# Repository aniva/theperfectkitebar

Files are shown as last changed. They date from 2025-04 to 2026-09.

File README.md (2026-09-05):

# ThePerfectKiteBar (TPKB)

A **DIY kite control bar with shared design files** designed for **kite-foil enthusiasts** who value flexibility, customization, and field serviceability.

Development began in **2023**, driven by the lack of suitable off-the-shelf products—most commercial options were either too expensive, overly complex, unnecessarily heavy, or built around identical designs across multiple brands.
The first functional version of TPKB was **tested in Spring 2024**, followed by multiple iterative refinements based on real-world user experience.

Key design priorities include:
- Minimal weight without compromising strength
- Full **field-serviceability** with common tools
- **Low-cost manufacturing** using accessible 3D printing services
- Easy **spare part replacement**
- **Glove-friendly operation**, especially in cold water (5°C and below)
- Seamless usability in both **cold northern climates** and **tropical destinations** (e.g., the Caribbean)

---

## Project Purpose

ThePerfectKiteBar is a hardware design project focused on designing and sharing components of a kite control bar system optimized for kite-foiling.

This project is intended for:

- DIY enthusiasts
- Riders seeking lightweight or custom solutions
- Experimental design exploration
- Field replacement and customization of bar components

All parts are designed with parametric flexibility in mind—allowing for adaptation to different materials, manufacturing methods, and rope/tube sizes.

---

## License and Project Management

Design files and documentation are shared under [CC BY-NC 4.0](LICENSE.md), which requires attribution and restricts commercial use.

See [Contributing](CONTRIBUTING.md) for the change workflow and local checks, and [Validation Status](docs/validation.md) for recorded testing status and outstanding validation work.

## Project Organization and Directory Structure

The main hardware components of the project are organized under the `/hardware/` directory:

- `/hardware/bar/` → Bar components, including the main tube, end pieces, and center inserts
- `/hardware/swivel/` → Swivel component for untwisting lines
- `/hardware/quick_release/` → The quick release safety system
- `/hardware/trim/` → Depower trim system, including the V-splitter
- `/hardware/tools/` → Jigs and tools for assembly

Each component has its own folder containing:

- Its own `README.md` file with detailed specifications
- Subfolders indicating key design constraints (tube diameter, bearing type, rope diameter, etc.)
- Variants reflecting different design approaches

---

## Design Philosophy: Variant vs Version

| Term | Meaning | How it's handled |
| --- | --- | --- |
| Variant | Different design direction or conceptual approach | Separate folder or filename indication |
| Version | Evolution of the same variant (small changes, tweaks, improvements) | Managed via Git version control |

**Example Filename Breakdown:**

```text
bar/carbon_tube_od24_id22mm/bar_end/leader_line_3mm/variant_7/bar-end_24_22_sls.*
```

- `bar` folder = part of the bar (vs QR etc.)
- `carbon_tube_od24_id22mm` = must use carbon tube with these OD/ID dimensions
- `leader_line_3mm` = must use 3mm leader (steering) lines 
- `variant` = 7 
- `version` = _git commit id_

---

## Navigation Guide

To explore any component:

1. Navigate to `hardware/<component_name>/` and open the `README.md` file in that directory
2. Inside you will find:
   - Part purpose and function
   - Design constraints and specifications
   - 3D printing instructions
   - Assembly notes and requirements
   - Images and previews
   - Available variants

**Component Links:**

- [Bar](hardware/bar/README.md)
- [Swivel](hardware/swivel/README.md)
- [Quick Release](hardware/quick_release/README.md)
- [Trim](hardware/trim/README.md)
- [Tools](hardware/tools/README.md)
- [Rope Splicing & Cutting Dimensions Guide](docs/rope_dimensions.md)
- [Interactive Splicing & Sizing Calculator](https://raw.githack.com/aniva/theperfectkitebar/main/docs/rope_calculator.html)
- [Bungee & Accessory Sizing Guide](https://raw.githack.com/aniva/theperfectkitebar/main/docs/rope_calculator.html)

---

## General 3D Print Material Selection Guide

Material selection must consider ductility, impact resistance, print orientation, and cyclic loading as well as tensile strength. The recommendations below incorporate the expanded JLC3DP SLS and MJF catalog; supplier specifications were checked on **2026-09-05**.

**3301PA is the recommended SLS choice for new bar ends and center inserts**, including white parts previously specified in 1172 Pro. **PA11-HP is preferred for new V-splitters carrying direct line tension, with PA12-HP retained as the existing alternative.** PA12-HP remains the baseline for cleat bases. Consider PA12S-HP for lightly loaded MJF accessories when the actual quote offers a saving.

The project previously reported multi-season field use of 3201PA-F from -20°C to +30°C in freshwater, seawater, and snow. That experience does not transfer automatically to another material. The newer recommendations are material-selection decisions, not recorded TPKB field validation; see [Validation Status](docs/validation.md). Component-specific geometry, metal hardware, and assembly requirements still apply.

### Material Recommendations by Use Case

| Part / Component | Recommended Material | Manufacturing Technology | Notes |
|---|---|---|---|
| Bar ends and center inserts, including white parts | [3301PA Nylon](https://jlc3dp.com/help/article/3301pa-nylon) | SLS | Recommended for new builds; 48 MPa tensile strength and 30% elongation. Higher listed elongation than 1172 Pro, but not than the current 3201PA-F specification. Verify fit, line wear, and impact behavior on the finished part. |
| Existing black SLS parts / established material option | [3201PA-F Nylon](https://jlc3dp.com/help/article/3201pa-f-nylon) | SLS | Retain as an alternative backed by the project's reported field experience. Current supplier figures are 44 MPa and 35% elongation. |
| Existing white SLS parts | [Precimid 1172 Pro](https://jlc3dp.com/help/article/precimid-1172-pro) | SLS | Legacy white option; 46 MPa and 8–15% elongation. Prefer evaluating 3301PA for new bar ends and center inserts. |
| V-splitters carrying direct kite-line tension | [PA11-HP Nylon](https://jlc3dp.com/help/article/pa11-hp-nylon) preferred; [PA12-HP](https://jlc3dp.com/help/article/pa12-hp-nylon) existing alternative | MJF | Prefer PA11-HP for new builds based on its higher listed tensile strength, elongation, and notched impact strength. Validate the finished part under representative line loads, including sustained-load creep and line-hole wear. Do not substitute PA12S solely to reduce cost. |
| Cleat bases | [PA12-HP Nylon](https://jlc3dp.com/help/article/pa12-hp-nylon) | MJF | Retain the existing baseline; evaluate PA11-HP separately for fit and loaded operation. |
| Lightly loaded housings, covers, and slider blocks without significant shock loading | [PA12S-HP Nylon](https://jlc3dp.com/help/article/pa12s-hp-nylon) | MJF | Potential cost-saving choice with a finer surface texture. Account for orientation: elongation is 12% in XY but only 5% in Z. Compare actual part quotes. |
| Polymer components requiring greater ductility | [PA11-HP Nylon](https://jlc3dp.com/help/article/pa11-hp-nylon) | MJF | Candidate for testing: 52 MPa and 50% elongation. A QR housing substitution requires assembly and release-function testing. This is not a recommendation to replace metal pins or load-bearing metal mechanisms with nylon. |
| Swivel metal parts (housing and shaft) | [Titanium TC4](https://jlc3dp.com/help/article/titanium-tc4) or [316L Stainless Steel](https://jlc3dp.com/help/article/316L-Stainless-Steel) | SLM | Titanium for lower weight; otherwise 316L stainless steel, following component specifications. |
| Quick Release (QR) mechanism flat parts | Titanium sheet | Laser or waterjet cutting | Use the exact thickness specified in the component instructions. |
| Assembly tools | Refer to [Tools](hardware/tools/README.md) | SLM and SLA | Follow each tool's requirements; CBY resin remains an economical option for suitable jig adapters and presser feet. |

### Supplier Property Comparison

These are supplier coupon-test values, not allowable loads for the printed components. XY and Z identify print orientation; test methods and specimen conditioning differ between materials. Higher elongation alone does not establish better fatigue life or impact performance.

| Technology | Material / Supplier Source | Tensile Strength | Elongation at Break | Selection Notes |
|---|---|---|---|---|
| MJF | [PA12-HP](https://jlc3dp.com/help/article/pa12-hp-nylon) | 48 MPa | 20% | Existing structural baseline. |
| MJF | [PA12S-HP](https://jlc3dp.com/help/article/pa12s-hp-nylon) | 45 MPa XY; 43 MPa Z | 12% XY; 5% Z | Finer texture; lower ductility. Its listed 1700 MPa tensile modulus is lower than PA12-HP's 1800 MPa. |
| MJF | [PA11-HP](https://jlc3dp.com/help/article/pa11-hp-nylon) | 52 MPa XY/Z | 50% XYZ | Preferred for new V-splitters; validate the finished component. |
| MJF | [PAC-HP](https://jlc3dp.com/help/article/pac-hp-nylon) | Not listed on linked page | Not listed on linked page | JLC3DP describes full-color nylon for models and prototypes, not carbon-fiber-filled nylon. Excluded from structural recommendations. |
| SLS | [3201PA-F](https://jlc3dp.com/help/article/3201pa-f-nylon) | 44 MPa | 35% | Current figures differ from the supplied research's 45–48 MPa and 10–15%. |
| SLS | [1172 Pro](https://jlc3dp.com/help/article/precimid-1172-pro) | 46 MPa | 8–15% | Existing white material. |
| SLS | [3301PA](https://jlc3dp.com/help/article/3301pa-nylon) | 48 MPa | 30% | White; selected for new bar ends and center inserts. |
| SLS | [3401GB](https://jlc3dp.com/help/article/3401gb-nylon) | 42 MPa | 8% | 2500 MPa tensile modulus. Not selected for impact-prone kite-bar parts because this project prioritizes ductility over increased stiffness. |

### Cost, Exposure, and Manufacturing Notes

- **Cost:** JLC3DP lists starting prices of $1 for the linked PA12-HP, PA12S-HP, PA11-HP, 3201PA-F, 1172 Pro, and 3301PA materials. These minimum prices do not establish equal finished-part costs or a guaranteed PA12S saving; compare quotes for the same geometry and quantity.
- **Marine exposure:** The linked specifications do not establish comparative long-term UV, saltwater, cold-water, or fatigue performance for these TPKB parts. Record representative exposure and loading results before describing a replacement material as field-proven. PA11's ductility is not a guarantee against fracture.
- **Print review:** Evaluate supplier dimensional or wall-thickness warnings against the affected part's fit and loading requirements. Do not dismiss a warning solely because a previous print worked. See the [example supplier warning](images/jlc3dp_warning.jpeg).

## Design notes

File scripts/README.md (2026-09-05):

# Developer Automation & Git Hooks

This directory contains utility scripts and Git hooks that automate local CAD file management, keep documentation in sync with cloud storage, and clean up workspace metadata.

## The Big Picture: Why are hooks needed?

Git tracks manufacturing exports such as `.stl`, `.step`, and `.dxf`. Editable `.shapr` sources are excluded from Git and hosted in the Google Cloud Storage (GCS) bucket `theperfectkitebar-cad-assets`.

To make collaboration smooth, we use scripts and a Git hook to:
1. **Sync Assets (manual script)**: Fetch latest CAD files from GCS to your local `hardware/` directory.
2. **Synchronize Docs**: Keep download links, file hashes (MD5), and modification dates in README files automatically in sync with the files stored on GCS.
3. **Clean Metadata**: Strip hidden OS and cloud sync files (e.g. Windows `:Zone.Identifier` or Dropbox attributes) from the repository before commits.

---

## Installation

To set up the automated hooks on your local machine, run:

```bash
./scripts/hooks/install_hooks.sh
```

This script installs executable hooks in Git’s configured hooks directory, using absolute symlinks into this checkout. It repairs stale symlinks and refuses to overwrite an existing regular hook file. Rerun it after moving the checkout.

---

## Script Reference

### Hooks
* **`install_hooks.sh`**: Installs symlinks from `.git/hooks/` to the project's scripts.
* **`pre-commit.sh`** (runs automatically before each commit):
  * Cleans up OS/Dropbox metadata files (`:Zone.Identifier`, `:com.dropbox.attrs`) to prevent Git pollution.
  * Runs `update_shapr_tables.py` to auto-generate markdown download tables in component READMEs.
  * Automatically stages READMEs whose generated tables change. This stages the entire file, so finish or separate unrelated README edits before committing.
  * Works without an interactive terminal and succeeds when no table updates are needed. If GCS metadata is unavailable, the updater reports it and leaves tables unchanged.

### Python Utilities
* **`update_shapr_tables.py`**:
  * Scans local directories for `.shapr` source files.
  * Fetches file metadata (MD5 hashes, last-modified dates) from the GCS JSON API.
  * Dynamically updates markdown tables inside READMEs between `<!-- BEGIN_SHAPR_TABLE -->` and `<!-- END_SHAPR_TABLE -->` tags.
* **`sync_from_gcs.py`**:
  * Syncs public GCS assets locally into your `hardware/` directory.
  * Compares local MD5 hashes with GCS metadata to perform smart, delta-only updates.
  * Backs up overwritten files into timestamped local `backup/` folders so you never lose local edits.

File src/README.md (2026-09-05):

# Google Cloud Infrastructure & Functions

This directory contains the Terraform configuration and Python Cloud Functions to deploy and manage the public asset hosting infrastructure for ThePerfectKiteBar.

## The Big Picture: Egress Cost Protection

Hosting CAD models (`.stl`, `.step`, `.shapr`) for public download on Google Cloud Storage (GCS) can lead to unpredictable bandwidth egress costs if the designs become popular. To ensure the project remains cost-controlled, this infrastructure automatically revokes public access when a budget limit is hit.

```mermaid
graph TD
    Alert[Budget Alert Exceeded] -->|Pub/Sub| DisableFn[disablePublicAccess Cloud Function]
    DisableFn -->|IAM Update| Bucket[(GCS Asset Bucket)]
    
    Scheduler[Cloud Scheduler Job <br/> 1st of the month] -->|HTTP POST| EnableFn[enablePublicAccess Cloud Function]
    EnableFn -->|IAM Update| Bucket
```

---

## Infrastructure Architecture

The infrastructure consists of:

1. **GCS Asset Bucket (`theperfectkitebar-cad-assets`)**: Public bucket where CAD files are stored and served.
2. **GCS Code Bucket (`theperfectkitebar-fn-code`)**: Private bucket where zipped Cloud Function code is uploaded.
3. **Pub/Sub Topic (`cad-budget-alerts`)**: Connects to the GCP Billing Budget so that alerts publish messages to this topic.
4. **Cloud Scheduler Job (`reenable-public-access`)**: Runs monthly to trigger the enabling function.

### Cloud Functions (Python 3.12 / Gen 2)

* **`disablePublicAccess`**:
  * **Trigger**: Subscribed to the `cad-budget-alerts` Pub/Sub topic.
  * **Action**: Parses the budget alert payload. If the display name matches the configured budget and the alert threshold is exceeded, it removes `allUsers` from the `roles/storage.objectViewer` binding on the asset bucket (effectively disabling public downloads).
* **`enablePublicAccess`**:
  * **Trigger**: HTTP POST endpoint.
  * **Action**: Adds the `allUsers` member back to the bucket's `roles/storage.objectViewer` policy binding, restoring public downloads.

---

## File Reference

* **`cad2gcp/`**: The primary Terraform module containing infrastructure resource definitions.
* **`cad2gcp/src/main.py`**: Function entry points that dispatch to the handlers.
* **`cad2gcp/src/disable_public_access.py`**: Budget-alert handler that removes public access.
* **`cad2gcp/src/enable_public_access.py`**: HTTP handler that restores public access.
* **`cad2gcp/variables.tf`**: Input variables, including the budget display name.

The Terraform module defines the Pub/Sub topic but does not create the billing budget. Configure that budget separately to publish to `cad-budget-alerts`, using the matching display name. These files describe the intended deployment; they do not establish its current live status.

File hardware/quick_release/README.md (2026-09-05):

# Quick release

The Quick Release (QR) is a critical safety component of the kite control system. This design focuses on reliability, ease of use (even with gloves in cold water), and field serviceability.

The mechanism consists of 3D-printed parts and flat-cut metal components.

-   **Case**: The main body of the QR is designed for SLS 3D printing in Nylon (e.g., PA12 or Precimid-1172 Pro for a white finish) for durability and impact resistance.
-   **Mechanism**: The internal flat parts are designed to be laser or waterjet cut from Grade 5 Titanium sheets of specific thicknesses (0.125" and 0.187") for maximum strength and corrosion resistance.

This directory contains variants of the QR system that accommodate different bolt sizes (M4 and M6) for attachment.

Below are two images showing the Quick Release in its closed (locked) and open (released) positions. It functions like any standard push-away quick release system used in kitesurfing.

<table>
  <tr>
    <td align="center"><strong>Closed Position</strong></td>
    <td align="center"><strong>Open Position</strong></td>
  </tr>
  <tr>
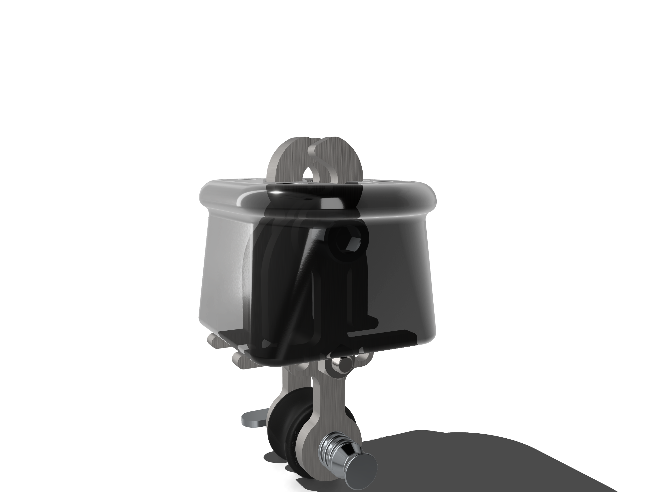
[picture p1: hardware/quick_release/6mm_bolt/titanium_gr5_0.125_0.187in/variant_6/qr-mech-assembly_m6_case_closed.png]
    <td></td>
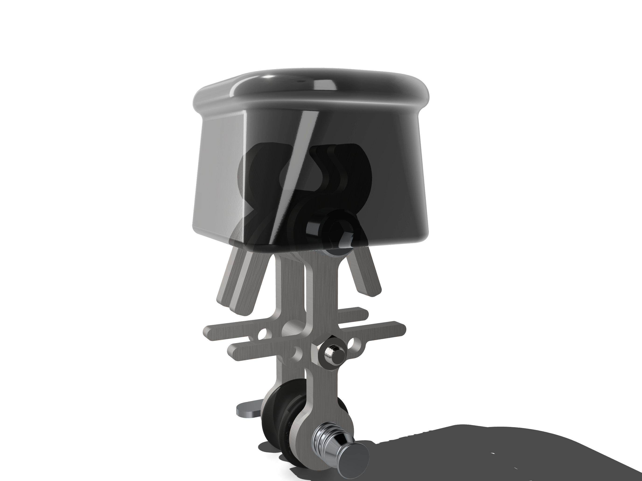
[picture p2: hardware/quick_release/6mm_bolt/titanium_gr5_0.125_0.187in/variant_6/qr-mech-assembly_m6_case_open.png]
    <td></td>
  </tr>
</table>

## Sizing (M4 vs. M6)

The M4 and M6 versions are functionally identical across all variants, with the only difference being the diameter of the attachment bolt.

-   **M4 Version**: A lighter-weight option suitable for most recreational riders.
-   **M6 Version**: A heavier-duty option suitable for heavier riders or more demanding conditions.

Note that for all variants, the upper nut (M4 or M6) that holds the claws must be installed permanently (e.g., using Loctite Threadlocker Red).

See [Validation Status](../../docs/validation.md) for recorded evidence and outstanding testing work.

## Variants

Variants 1 through 4 have been omitted, as they represent early design iterations that did not proceed to field testing.

### Variant 5 M4

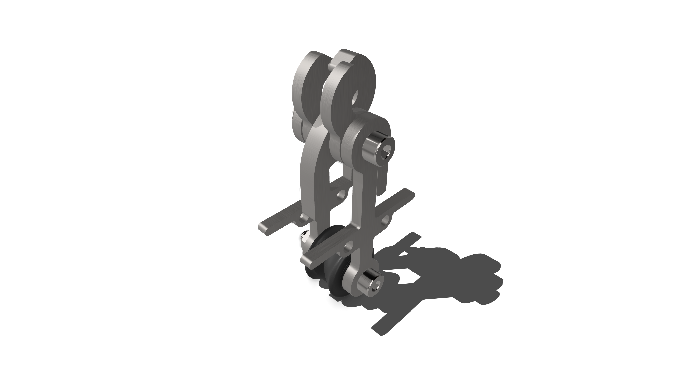
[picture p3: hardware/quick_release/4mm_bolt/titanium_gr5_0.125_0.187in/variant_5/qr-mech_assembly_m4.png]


This variant uses a permanent M4 bolt and nut to attach to the harness's sliding rope. It is recommended to use a thread-locking fluid (e.g., Loctite Threadlocker Red) to secure the nut.

Parts needed to build the **M4** version of this variant.

From any laser/waterjet cutting service (e.g., SendCutSend)

| File Name | Parameters | Quantity | Image
|---|---|---|---|
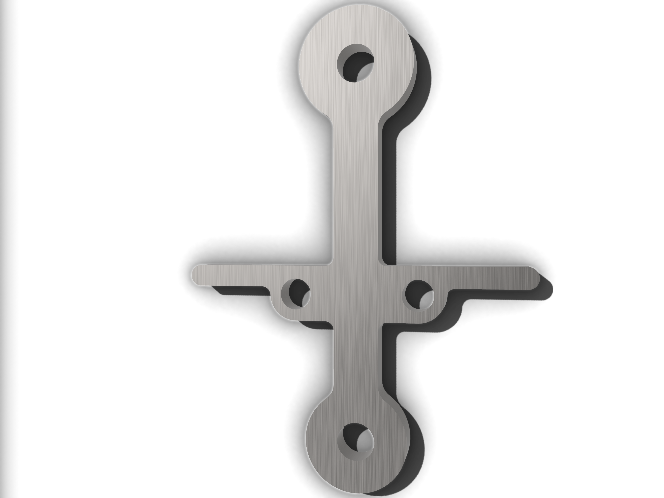
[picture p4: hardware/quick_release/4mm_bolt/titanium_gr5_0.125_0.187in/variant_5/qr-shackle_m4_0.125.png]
| [`qr-shackle_m4.dx`](./4mm_bolt/titanium_gr5_0.125_0.187in/variant_5/qr-shackle_m4.dxf) | Material: Grade 5 Titanium, Thickness: 0.125" | 2 pieces ||
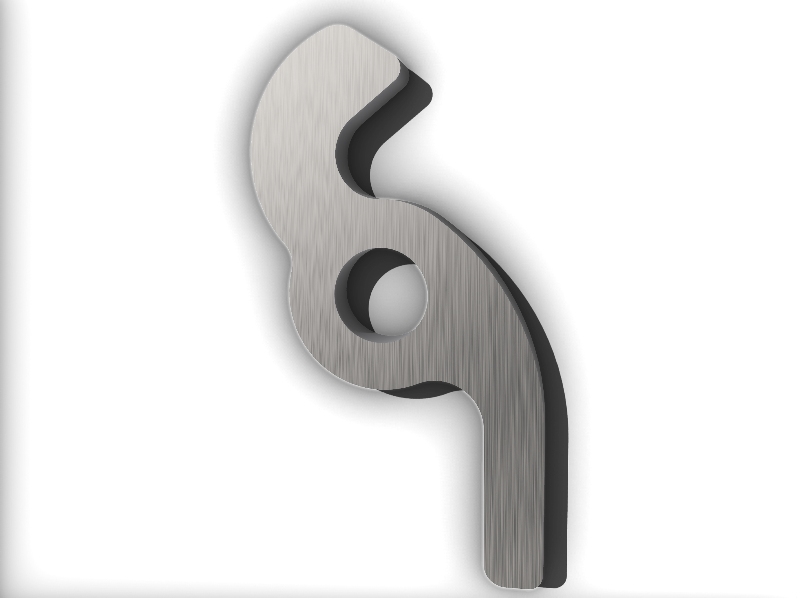
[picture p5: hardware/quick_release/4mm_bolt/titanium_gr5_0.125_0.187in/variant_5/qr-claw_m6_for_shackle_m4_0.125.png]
| [`qr-claw_m6_for_shackle_m4.dxf`](./4mm_bolt/titanium_gr5_0.125_0.187in/variant_5/qr-claw_m6_for_shackle_m4.dxf) | Material: Grade 5 Titanium, Thickness: 0.125" | 2 pieces ||
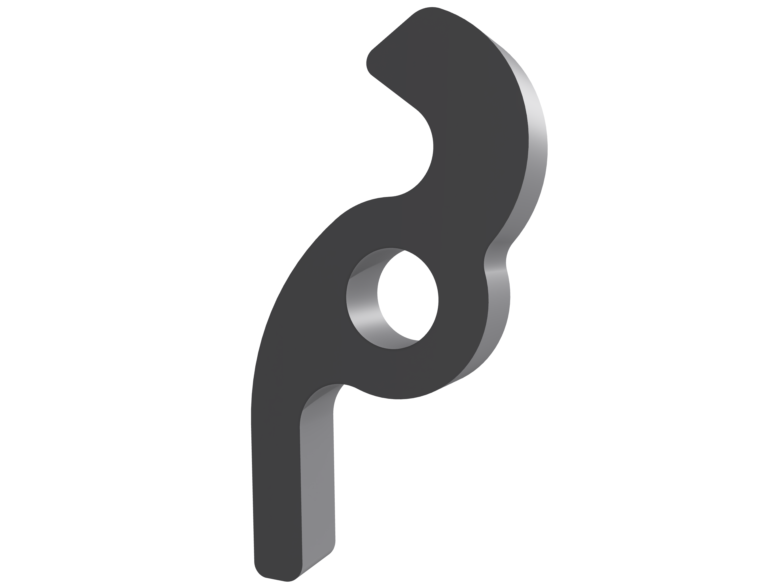
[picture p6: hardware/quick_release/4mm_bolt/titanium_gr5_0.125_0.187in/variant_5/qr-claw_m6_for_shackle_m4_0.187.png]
| [`qr-claw_m6_for_shackle_m4.dxf`](./4mm_bolt/titanium_gr5_0.125_0.187in/variant_5/qr-claw_m6_for_shackle_m4.dxf) | Material: Grade 5 Titanium, Thickness: 0.187" | 1 piece ||

From a print shop with SLS 3D printing technology (e.g., jlc3dp.com)

| File Name | Parameters | Quantity | Image |
|---|---|---|---|
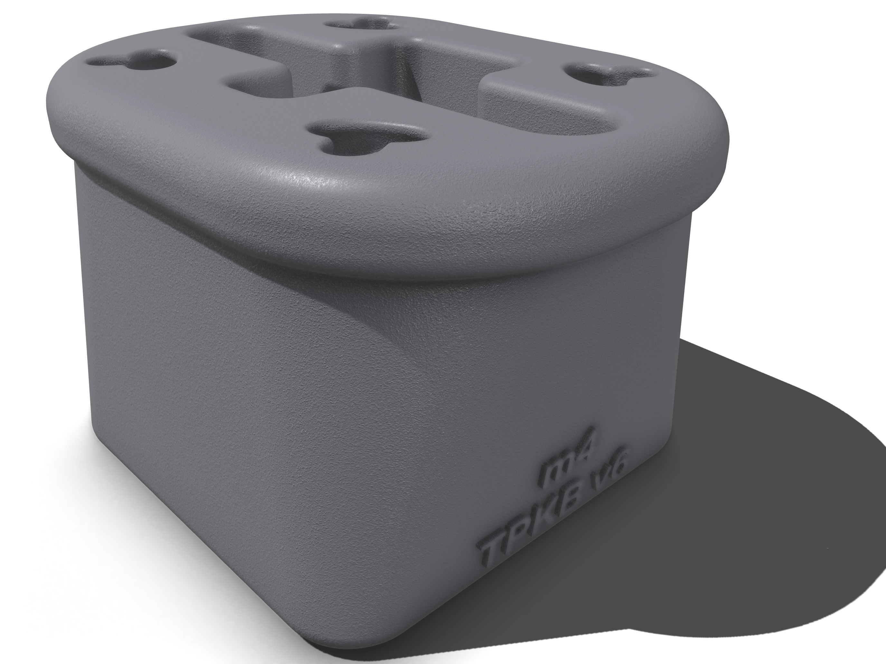
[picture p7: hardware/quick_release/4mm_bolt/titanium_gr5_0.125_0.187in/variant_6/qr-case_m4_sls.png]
| [`qr-case_m4_sls.stl`](./4mm_bolt/titanium_gr5_0.125_0.187in/variant_6/qr-case_m4_sls.stl) | Material 3201PA-F Nylon or 1172Pro Nylon | 1 piece || 
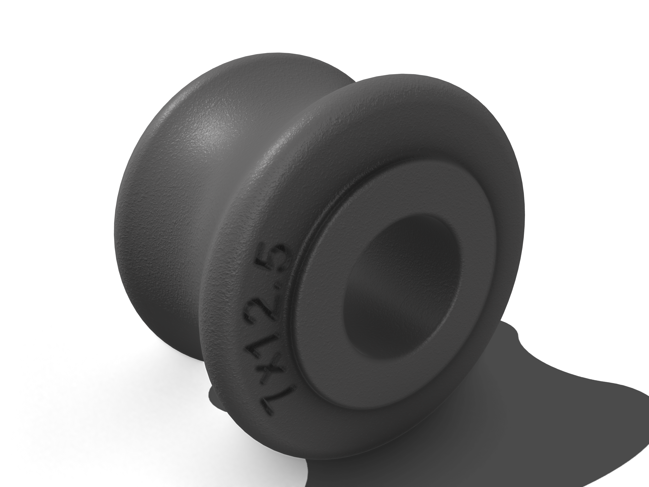
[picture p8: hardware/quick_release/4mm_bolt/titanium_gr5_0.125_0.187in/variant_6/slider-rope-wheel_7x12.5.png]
| [`slider-rope-wheel_7x12.5.stl`](./4mm_bolt/titanium_gr5_0.125_0.187in/variant_6/slider-rope-wheel_7x12.5.stl) | Material 3201PA-F Nylon or 1172Pro Nylon | 1 piece ||

Additional parts can be procured from hardware suppliers such as aliexpress.com, amazon.com, or McMaster-Carr.

- Marine grade stainless or titanium socket head bolts M4 lengh of 25mm - 2 bolts and 2 nuts
- Titanium tube for two 13mm spacers with an outer diameter (OD) of 6mm and an inner diameter (ID) of 4mm.
- 2.5mm Elastic Nylon Bungee Cord. A length of ~35cm (approx. 1 ft 2 in) is needed per QR. (Example: Paracord Planet Elastic Nylon Bungee and Shock Cord)

### Variant 5 M6

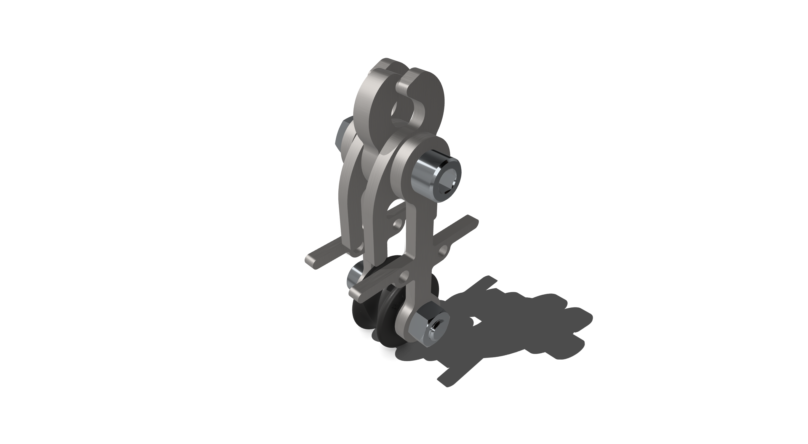
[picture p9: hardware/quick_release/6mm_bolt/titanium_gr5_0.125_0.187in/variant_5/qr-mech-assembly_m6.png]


This variant uses a permanent M6 bolt and nut to attach to the harness's sliding rope. It is recommended to use a thread-locking fluid (e.g., Loctite Threadlocker Red) to secure the nut.

Parts needed to build the **M6** version of this variant.

From any laser/waterjet cutting service (e.g., SendCutSend)

| File Name | Parameters | Quantity | Image |
|---|---|---|---|
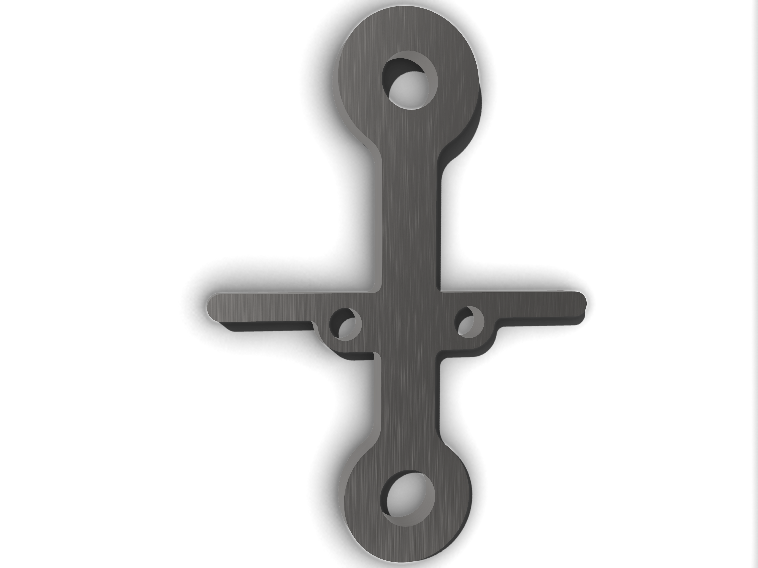
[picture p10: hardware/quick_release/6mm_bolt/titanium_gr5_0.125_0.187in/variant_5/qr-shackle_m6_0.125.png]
| [`qr-shackle_m6.dxf`](./6mm_bolt/titanium_gr5_0.125_0.187in/variant_5/qr-shackle_m6.dxf) | Material: Grade 5 Titanium, Thickness: 0.125" | 2 pieces ||
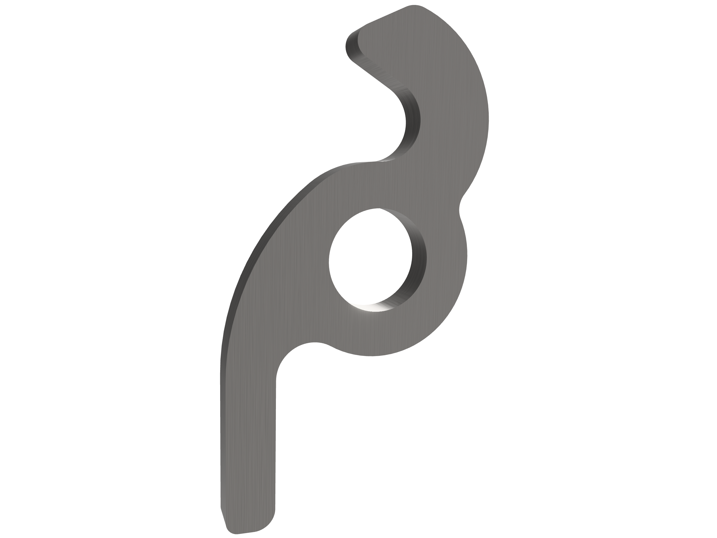
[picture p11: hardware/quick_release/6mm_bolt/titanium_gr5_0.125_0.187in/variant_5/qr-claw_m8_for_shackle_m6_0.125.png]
| [`qr-claw_m8_for_shackle_m6.dxf`](./6mm_bolt/titanium_gr5_0.125_0.187in/variant_5/qr-claw_m8_for_shackle_m6.dxf) | Material: Grade 5 Titanium, Thickness: 0.125" | 2 pieces ||
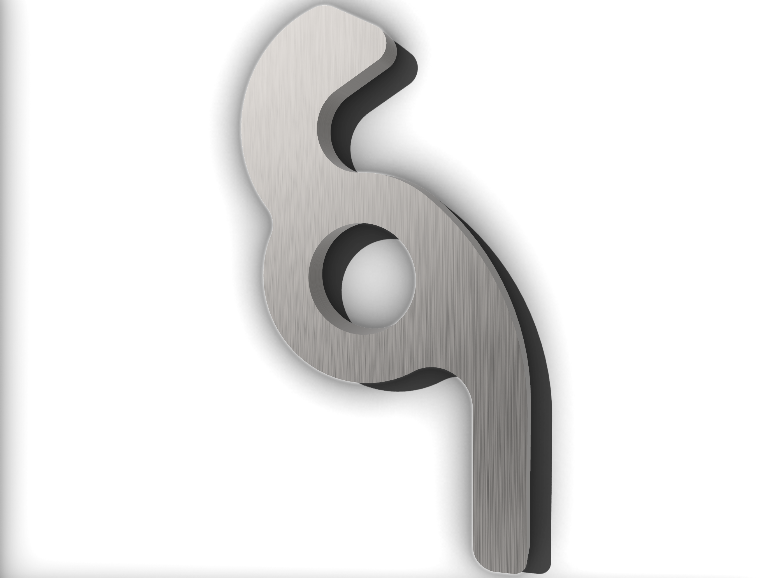
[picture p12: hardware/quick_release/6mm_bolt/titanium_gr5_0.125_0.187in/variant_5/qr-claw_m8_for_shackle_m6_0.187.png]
| [`qr-claw_m8_for_shackle_m6.dxf`](./6mm_bolt/titanium_gr5_0.125_0.187in/variant_5/qr-claw_m8_for_shackle_m6.dxf) | Material: Grade 5 Titanium, Thickness: 0.187" | 1 piece ||

From a print shop with SLS 3D printing technology (e.g., jlc3dp.com)

| File Name | Parameters | Quantity | Image |
|---|---|---|---|
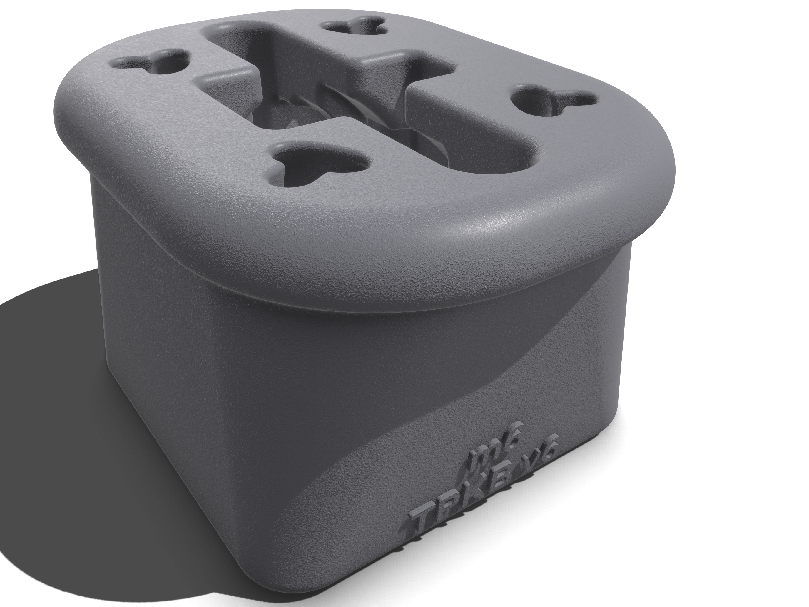
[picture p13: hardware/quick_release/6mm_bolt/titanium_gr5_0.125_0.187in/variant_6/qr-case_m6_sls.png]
| [`qr-case_m6_sls.stl`](./6mm_bolt/titanium_gr5_0.125_0.187in/variant_6/qr-case_m6_sls.stl) | Material 3201PA-F Nylon or 1172Pro Nylon | 1 piece || 
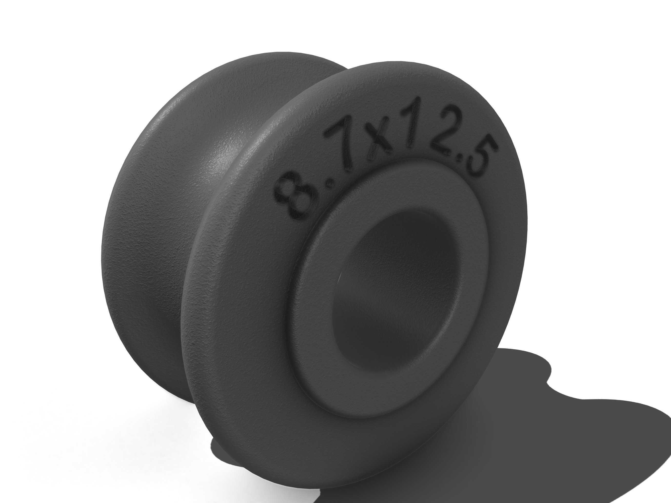
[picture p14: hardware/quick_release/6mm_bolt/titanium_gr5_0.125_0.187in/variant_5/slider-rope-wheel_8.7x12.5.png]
| [`slider-rope-wheel_8.7x12.5.stl`](./6mm_bolt/titanium_gr5_0.125_0.187in/variant_5/slider-rope-wheel_8.7x12.5.stl) | Material 3201PA-F Nylon or 1172Pro Nylon | 1 piece ||

Additional parts procured from hardware suppliers, e.g. aliexpress.com, amazon.com, or [macmastercarr](https://www.mcmaster.com/)

- Marine grade stainless or titanium socket head bolts M6 lengh of 25mm - 2 bolts and 2 nuts
- Titanium tube for two spacers of 13mm with OD 8mm and ID 6mm
- 2.5mm Elastic Nylon Bungee Cord. A length of ~35cm (approx. 1 ft 2 in) is needed per QR. (Example: Paracord Planet Elastic Nylon Bungee and Shock Cord)

### Variant 6

This variant uses a quick release pin, allowing for easy removal of the QR from a harness hook or sliding rope in the field.

To support QR structure an additional spacer with M4 bolt and nut used that must be instaled permanently (e.g.,using Loctite Threadlocker Red).

Note that all the claws are the same as for Variant 5 with correspoing M4 or M6 bolt and nut.

QR cases are also the same and rope wheel is of M4 version (because quick release pin diameter is M6, the M4 version of the wheel have hole diameter of 7mmm)

**Warning:** At the time of writing, this variant has not been field-tested. There is a risk that the quick release pin could be accidentally released during use. This would cause the kite to flag out on its safety line, potentially resulting in a long swim. Extreme riding and jumping are strongly discouraged until this variant has been thoroughly tested in various conditions.

### Variant 6 M4

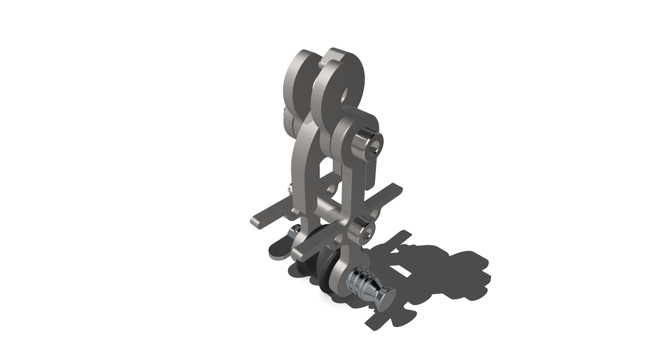
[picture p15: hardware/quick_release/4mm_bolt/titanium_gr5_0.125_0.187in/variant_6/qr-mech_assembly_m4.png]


Parts needed to build **M4** version of this variant.

From any laser/waterjet cutting service (e.g., SendCutSend)

| File Name | Parameters | Quantity | Image |
|---|---|---|---|
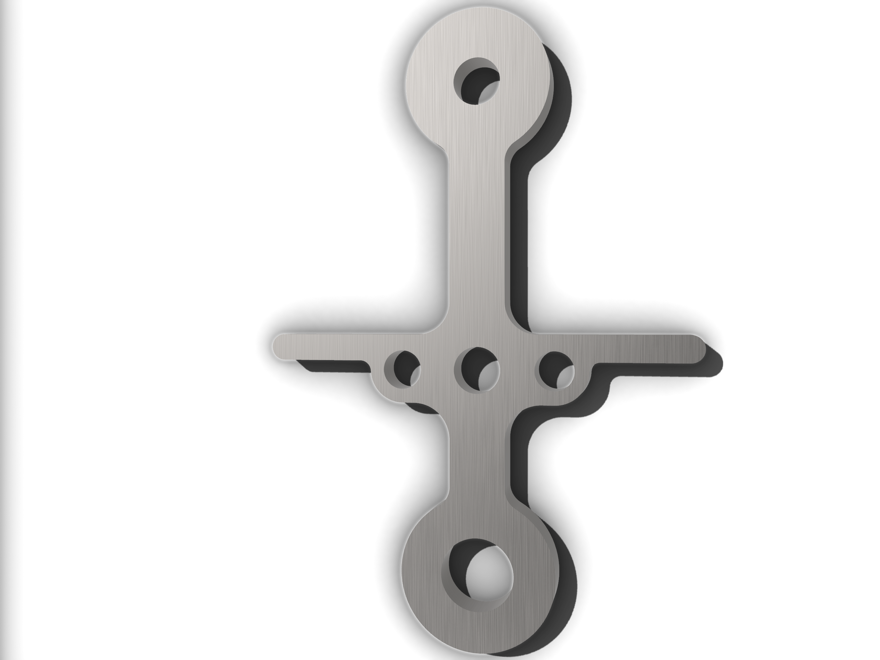
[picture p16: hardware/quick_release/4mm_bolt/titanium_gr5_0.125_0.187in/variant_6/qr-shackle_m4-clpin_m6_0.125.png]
| [`qr-shackle_m4-clpin_m6.dxf`](./4mm_bolt/titanium_gr5_0.125_0.187in/variant_6/qr-shackle_m4-clpin_m6.dxf) | Material: Grade 5 Titanium, Thickness: 0.125" | 2 pieces ||
| [`qr-claw_m6_for_shackle_m4.dxf`](./4mm_bolt/titanium_gr5_0.125_0.187in/variant_5/qr-claw_m6_for_shackle_m4.dxf) | Material: Grade 5 Titanium, Thickness: 0.125" | 2 pieces ||
| [`qr-claw_m6_for_shackle_m4.dxf`](./4mm_bolt/titanium_gr5_0.125_0.187in/variant_5/qr-claw_m6_for_shackle_m4.dxf) | Material: Grade 5 Titanium, Thickness: 0.187" | 1 piece ||

From a print shop with SLS 3D printing technology (e.g., jlc3dp.com)

| File Name | Parameters | Quantity | Image |
|---|---|---|---|
| [`qr-case_m4_sls.stl`](./4mm_bolt/titanium_gr5_0.125_0.187in/variant_6/qr-case_m4_sls.stl) | Material 3201PA-F Nylon or 1172Pro Nylon | 1 piece || 
| [`slider-rope-wheel_7x12.5.stl`](./4mm_bolt/titanium_gr5_0.125_0.187in/variant_6/slider-rope-wheel_7x12.5.stl) | Material 3201PA-F Nylon or 1172Pro Nylon | 1 piece ||

Additional parts procured from hardware suppliers, e.g. aliexpress.com, amazon.com, or [macmastercarr](https://www.mcmaster.com/)

- Marine grade stainless or titanium socket head bolts M4 lengh of 25mm - 2 bolts and 2 nuts.
- Titanium tube for two spacers of 13mm with OD 6mm and ID 4mm.
- Quick release pin, spring loaded, diameter 1/4" (or 6.35mm), usable length approx 1"
- 2.5mm Elastic Nylon Bungee Cord. A length of ~35cm (approx. 1 ft 2 in) is needed per QR. (Example: Paracord Planet Elastic Nylon Bungee and Shock Cord)

### Variant 6 M6

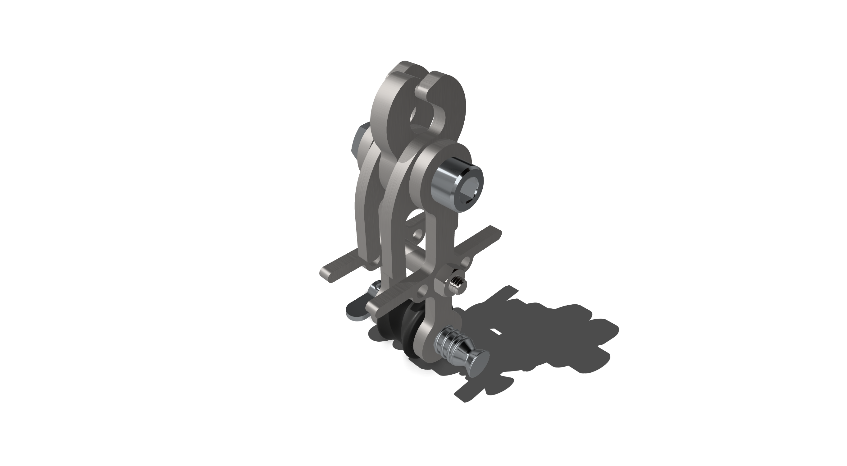
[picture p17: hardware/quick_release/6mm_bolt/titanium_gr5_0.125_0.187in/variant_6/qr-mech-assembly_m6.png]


Parts needed to build **M6** version of this variant.

From any laser/waterjet cutting service (e.g., SendCutSend)

| File Name | Parameters | Quantity | Image |
|---|---|---|---|
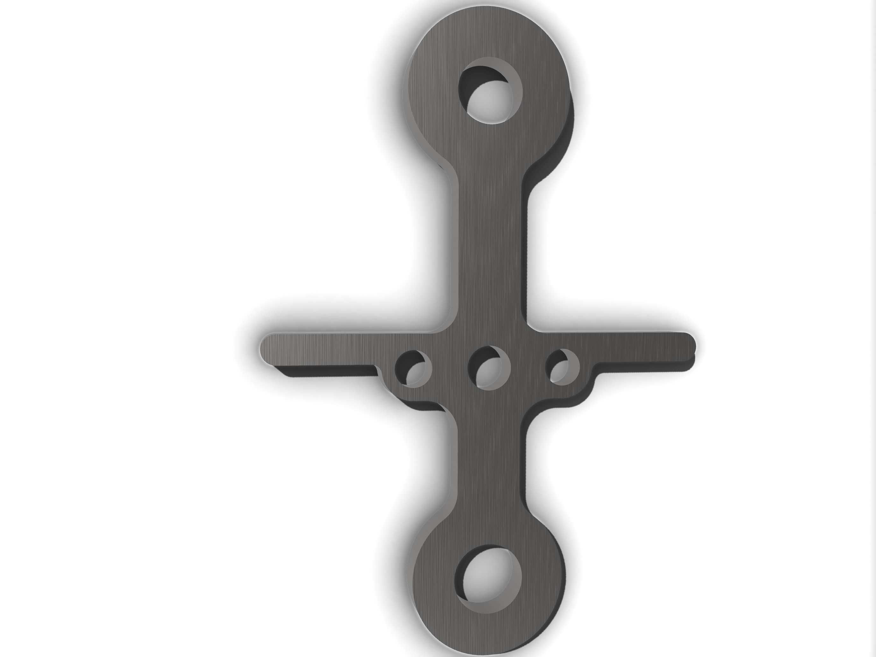
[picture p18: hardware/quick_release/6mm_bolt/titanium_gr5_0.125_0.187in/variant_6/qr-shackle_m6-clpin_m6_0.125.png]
| [`qr-shackle_m6-clpin_m6.dxf`](./6mm_bolt/titanium_gr5_0.125_0.187in/variant_6/qr-shackle_m6-clpin_m6.dxf) | Material: Grade 5 Titanium, Thickness: 0.125" | 2 pieces ||
| [`qr-claw_m8_for_shackle_m6.dxf`](./6mm_bolt/titanium_gr5_0.125_0.187in/variant_5/qr-claw_m8_for_shackle_m6.dxf) | Material: Grade 5 Titanium, Thickness: 0.125" | 2 pieces ||
| [`qr-claw_m8_for_shackle_m6.dxf`](./6mm_bolt/titanium_gr5_0.125_0.187in/variant_5/qr-claw_m8_for_shackle_m6.dxf) | Material: Grade 5 Titanium, Thickness: 0.187" | 1 piece ||

From a print shop with SLS 3D printing technology (e.g., jlc3dp.com)

| File Name | Parameters | Quantity | Image |
|---|---|---|---|
| [`qr-case_m6_sls.stl`](./6mm_bolt/titanium_gr5_0.125_0.187in/variant_6/qr-case_m6_sls.stl) | Material 3201PA-F Nylon or 1172Pro Nylon | 1 piece || 
| [`slider-rope-wheel_7x12.5.stl`](./4mm_bolt/titanium_gr5_0.125_0.187in/variant_6/slider-rope-wheel_7x12.5.stl) | Material 3201PA-F Nylon or 1172Pro Nylon | 1 piece ||

Additional parts procured from hardware suppliers, e.g. aliexpress.com, amazon.com, or [macmastercarr](https://www.mcmaster.com/)

- Marine grade stainless or titanium socket head bolts M6 lengh of 25mm - 1 bolt and 1 nut
- Titanium tube for one spacer of 13mm with OD 8mm and ID 6mm 
- Marine grade stainless or titanium socket head bolt M4 lengh of 25mm - 1 bolt and 1 nut
- Titanium tube for one spacer of 13mm with OD 6mm and ID 4mm
- Quick release pin, spring loaded, diameter 1/4" (or 6.35mm), usable length approx 1"
- 2.5mm Elastic Nylon Bungee Cord. A length of ~35cm (approx. 1 ft 2 in) is needed per QR. (Example: Paracord Planet Elastic Nylon Bungee and Shock Cord)

## Native Shapr3D Design Files

The following `.shapr` files are the editable source models created in Shapr3D. Each file includes full parametric definitions—sketches, constraints, and feature history—allowing you to open and modify them directly in Shapr3D (iOS/iPadOS/macOS).

<!-- BEGIN_SHAPR_TABLE -->
<!-- Auto-generated Shapr3D download table. Do not edit manually. -->
| File | MD5 | Last Modified | Download URL |
|---|-----|---|---|
| `qr-case_m4_sls.shapr` | `072ffdc4f512f3917c6d27e4810b86f3` | 2025-05-02 03:56:37 | [Download](https://storage.googleapis.com/theperfectkitebar-cad-assets/quick_release/4mm_bolt/titanium_gr5_0.125_0.187in/variant_6/qr-case_m4_sls.shapr) |
| `qr-mech_assembly_m4.shapr` | `f76e0f0c3568821b0a0b17119529330c` | 2025-05-02 03:56:34 | [Download](https://storage.googleapis.com/theperfectkitebar-cad-assets/quick_release/4mm_bolt/titanium_gr5_0.125_0.187in/variant_6/qr-mech_assembly_m4.shapr) |
| `qr-case_m6_sls.shapr` | `b3d09915740d8e98c3bd033677e449d8` | 2025-05-02 03:56:42 | [Download](https://storage.googleapis.com/theperfectkitebar-cad-assets/quick_release/6mm_bolt/titanium_gr5_0.125_0.187in/variant_6/qr-case_m6_sls.shapr) |
| `qr-mech_assembly_m6.shapr` | `c5754da631c5f340a9d5b38d51e96aca` | 2025-05-02 03:56:39 | [Download](https://storage.googleapis.com/theperfectkitebar-cad-assets/quick_release/6mm_bolt/titanium_gr5_0.125_0.187in/variant_6/qr-mech_assembly_m6.shapr) |
<!-- END_SHAPR_TABLE -->

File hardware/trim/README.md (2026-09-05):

# Trim Components

The **Trim** system allows the rider to adjust the power of the kite on the fly by changing the relative length of the front flying lines. It consists of the **V-Splitter** (which connects the depower line to the front lines) and the **Cleat Base** (which locks the trim adjuster line).

---

## 1. V-Splitters

The V-Splitter connects the single **sheeting (depower) line** to the two **front flying lines** (low V-split configuration). 

### Trim Symmetrical Guide
The top bar of the V-Splitter is designed to sit **perfectly horizontal** when the kite is at 12 o'clock. If the V-Splitter is tilted sideways, it visually signals to the rider that the lines are out of trim, indicating it's time to adjust.

### Sizing and Variant Breakdown
Different variants are optimized for specific sheeting rope and front flying line diameters:

| Sheeting Rope | Front Line | Variant | Description | CAD/3D Files | Preview Image |
|---|---|---|---|---|---|
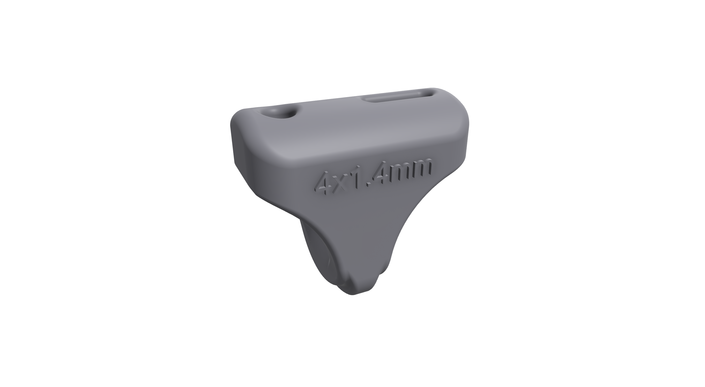
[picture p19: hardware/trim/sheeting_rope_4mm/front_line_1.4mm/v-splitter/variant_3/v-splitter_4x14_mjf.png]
| **4mm** | 1.4mm | **Variant 3** | **TPKB Standard.** Features smooth-radius safety line routing and reinforced structure. | [STEP](sheeting_rope_4mm/front_line_1.4mm/v-splitter/variant_3/v-splitter_4x14_mjf.step) \| [STL](sheeting_rope_4mm/front_line_1.4mm/v-splitter/variant_3/v-splitter_4x14_mjf.stl) |  |
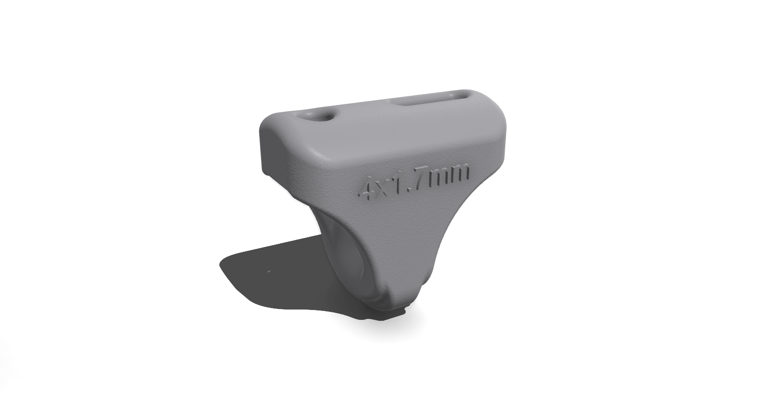
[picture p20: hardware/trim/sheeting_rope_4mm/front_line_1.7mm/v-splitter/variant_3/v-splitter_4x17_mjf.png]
| **4mm** | 1.7mm | **Variant 3** | **TPKB Heavy Duty.** Similar to the 1.4mm variant but optimized for thicker 1.7mm front lines. | [STEP](sheeting_rope_4mm/front_line_1.7mm/v-splitter/variant_3/v-splitter_4x17_mjf.step) \| [STL](sheeting_rope_4mm/front_line_1.7mm/v-splitter/variant_3/v-splitter_4x17_mjf.stl) |  |
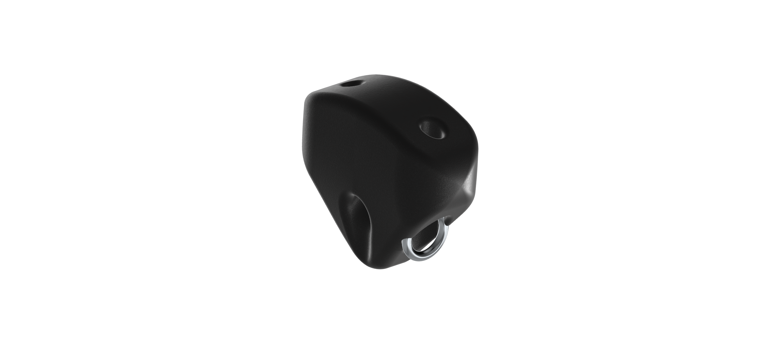
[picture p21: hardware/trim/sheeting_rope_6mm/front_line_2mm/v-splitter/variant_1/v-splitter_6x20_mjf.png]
| **6mm** | 2.0mm | **Variant 1** | Standard geometry designed for heavier 6mm depower lines and 2.0mm front lines. | [STEP](sheeting_rope_6mm/front_line_2mm/v-splitter/variant_1/v-splitter_6x20_mjf.step) \| [STL](sheeting_rope_6mm/front_line_2mm/v-splitter/variant_1/v-splitter_6x20_mjf.stl) |  |
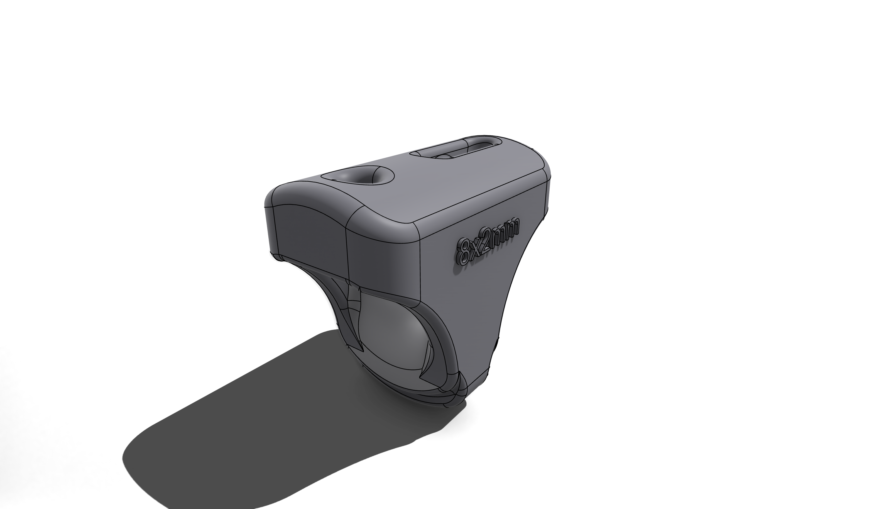
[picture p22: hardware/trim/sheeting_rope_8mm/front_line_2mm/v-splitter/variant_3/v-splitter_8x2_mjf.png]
| **8mm (Legacy)** | 2.0mm | **Variant 3** | Legacy compatibility part for thick 8mm depower lines on standard off-the-shelf bars. *Not used in standard TPKB.* | [STEP](sheeting_rope_8mm/front_line_2mm/v-splitter/variant_3/v-splitter_8x2_mjf.step) \| [STL](sheeting_rope_8mm/front_line_2mm/v-splitter/variant_3/v-splitter_8x2_mjf.stl) |  |

---

## 2. Cleat Base & Stopper

The **Cleat Base** mounts on the sheeting line directly below the V-Splitter. It houses the mechanical clam cleat to lock the trim adjustment rope securely in place under load. The matching **Trim Stopper** acts as a physical block to prevent the control bar from sliding too high.

### Sizing and Variant Breakdown
Designed specifically for the standard **4mm sheeting rope** track (Variant 3):

* **Cleat Base**: The main structural body housing the cleat.
  * **Files**: [STEP (Parametric)](sheeting_rope_4mm/cleat/variant_3/cleat-base_stopper_4_mjf.step) \| [STL (Print-Ready)](sheeting_rope_4mm/cleat/variant_3/cleat-base_4_mjf.stl)
* **Trim Stopper**: Installed on the sheeting line as a limit stop.
  * **Files**: [STL (Print-Ready)](sheeting_rope_4mm/cleat/variant_3/trim_stopper_4_mjf.stl)

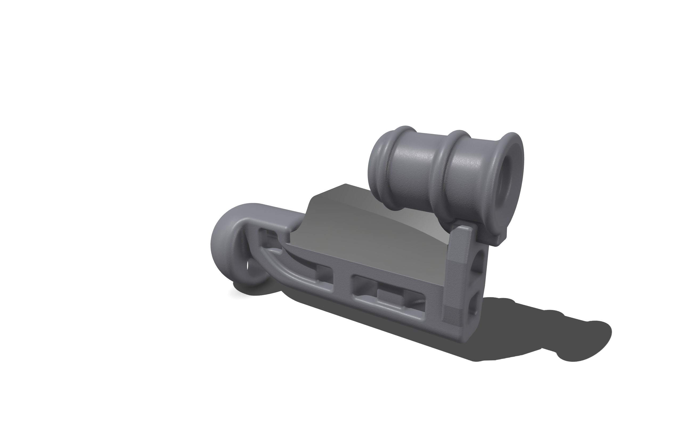
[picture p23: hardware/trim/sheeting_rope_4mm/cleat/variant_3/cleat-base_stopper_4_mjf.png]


## Manufacturing & Materials

* **Technology**: **Multi Jet Fusion (MJF)** is highly recommended. These are structural, high-stress parts that require isotropic strength and high dimensional accuracy.
* **Material**: **PA12 HP Nylon** (black or dark grey, unpolished or polished). Excellent UV and saltwater resistance.

---

## Native Shapr3D Design Files

The following `.shapr` files are the editable source models created in Shapr3D. Each file includes full parametric definitions—sketches, constraints, and feature history—so you can open and modify them directly in Shapr3D (iOS/iPadOS/macOS).

<!-- BEGIN_SHAPR_TABLE -->
<!-- Auto-generated Shapr3D download table. Do not edit manually. -->
| File | MD5 | Last Modified | Download URL |
|---|-----|---|---|
| `cleat-base_stopper_4_mjf.shapr` | `8448103e08f951ae36154b575d59a5ce` | 2025-06-07 20:08:35 | [Download](https://storage.googleapis.com/theperfectkitebar-cad-assets/trim/sheeting_rope_4mm/cleat/variant_3/cleat-base_stopper_4_mjf.shapr) |
| `line_stopper_14_mjf.shapr` | `4c48d73286f5f85ffe034c65127c51ed` | 2025-05-02 03:56:54 | [Download](https://storage.googleapis.com/theperfectkitebar-cad-assets/trim/sheeting_rope_4mm/front_line_1.4mm/safety_stopper/variant_3/line_stopper_14_mjf.shapr) |
| `v-splitter_4x14_mjf.shapr` | `20e751af154d15448be2f30b121adeea` | 2025-05-02 03:56:56 | [Download](https://storage.googleapis.com/theperfectkitebar-cad-assets/trim/sheeting_rope_4mm/front_line_1.4mm/v-splitter/variant_3/v-splitter_4x14_mjf.shapr) |
| `line_stopper_17_mjf.shapr` | `b019222a8a04ae55bade8134e7606bce` | 2025-05-02 03:56:45 | [Download](https://storage.googleapis.com/theperfectkitebar-cad-assets/trim/sheeting_rope_4mm/front_line_1.7mm/safety_stopper/variant_3/line_stopper_17_mjf.shapr) |
| `v-splitter_4x17_mjf.shapr` | `51b4313488d02281ff436c7bc2362fbe` | 2025-05-02 03:56:48 | [Download](https://storage.googleapis.com/theperfectkitebar-cad-assets/trim/sheeting_rope_4mm/front_line_1.7mm/v-splitter/variant_3/v-splitter_4x17_mjf.shapr) |
| `v-splitter_6x20_mjf.shapr` | `75c6516e03f86d0abf7c153b188e3ead` | 2025-06-07 20:08:35 | [Download](https://storage.googleapis.com/theperfectkitebar-cad-assets/trim/sheeting_rope_6mm/front_line_2mm/v-splitter/variant_1/v-splitter_6x20_mjf.shapr) |
| `v-splitter_8x2_mjf.shapr` | `4acd2d9fdaf139598083e8bd3fb39aa2` | 2026-09-05 21:31:12 | [Download](https://storage.googleapis.com/theperfectkitebar-cad-assets/trim/sheeting_rope_8mm/front_line_2mm/v-splitter/variant_3/v-splitter_8x2_mjf.shapr) |
<!-- END_SHAPR_TABLE -->

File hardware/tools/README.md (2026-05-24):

# Tools & Jigs

This directory provides CAD models and specifications for custom 3D-printed tools and jigs required to build, assemble, and maintain ThePerfectKiteBar. Having precise jigs ensures high-quality assembly and safe operation.

---

## 1. Drilling Jigs

The drilling jigs are designed to help you drill clean, centered, and perfectly aligned holes in your carbon fiber tube to install the central piece.

### Material Recommendations
* **Main Drill Guide**: Must be printed in **316L Stainless Steel** using **SLM** technology (Selective Laser Melting). The steel construction prevents the drill bit from eating into the guide.
* **Jig Adapters & Inserts**: Printed in **Photosensitive Resin** using **SLA** technology. Choose the size (22mm or 24mm) that matches your carbon tube.

### Parts list & Design Files
All drilling tools are located in [`drilling/2mm_bolt/`](drilling/2mm_bolt). You will need one main guide and a matching pair of alignment jigs and adapters for your tube diameter:

| Component | Tube Size | STEP (Parametric) | STL (Print-Ready) | Notes |
|---|---|---|---|---|
| **Main Drill Guide** | Universal | [drill-guide_od22-od24_slm.step](drilling/2mm_bolt/drill-guide_od22-od24_slm.step) | [drill-guide_od22-od24_slm.stl](drilling/2mm_bolt/drill-guide_od22-od24_slm.stl) | Metal insert guide. |
| **Alignment Jig** | OD 22mm | [alignment_jig_od22_sla.step](drilling/2mm_bolt/alignment_jig_od22_sla.step) | [alignment_jig_od22_sla.stl](drilling/2mm_bolt/alignment_jig_od22_sla.stl) | Guides the carbon tube. |
| **Alignment Jig** | OD 24mm | [alignment_jig_od24_sla.step](drilling/2mm_bolt/alignment_jig_od24_sla.step) | [alignment_jig_od24_sla.stl](drilling/2mm_bolt/alignment_jig_od24_sla.stl) | Guides the carbon tube. |
| **Drill Guide Adapter** | OD 22mm | [drill-guide-adapter_od22_sla.step](drilling/2mm_bolt/drill-guide-adapter_od22_sla.step) | [drill-guide-adapter_od22_sla.stl](drilling/2mm_bolt/drill-guide-adapter_od22_sla.stl) | Adapts guide to tube. |
| **Drill Guide Adapter** | OD 24mm | [drill-guide-adapter_od24_sla.step](drilling/2mm_bolt/drill-guide-adapter_od24_sla.step) | [drill-guide-adapter_od24_sla.stl](drilling/2mm_bolt/drill-guide-adapter_od24_sla.stl) | Adapts guide to tube. |

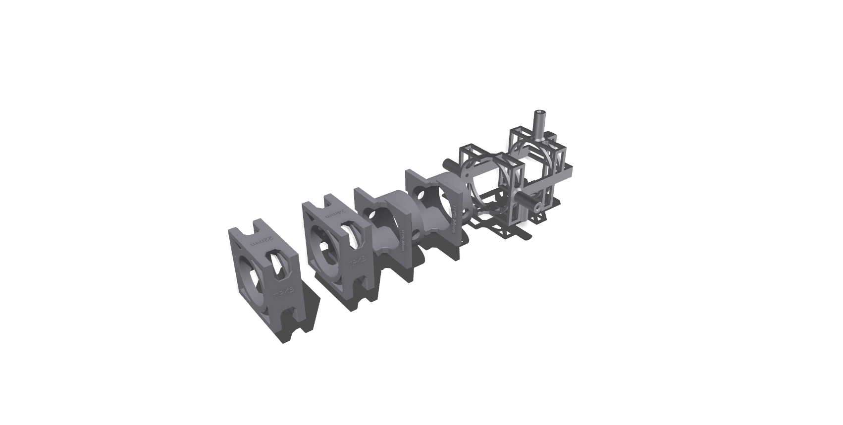
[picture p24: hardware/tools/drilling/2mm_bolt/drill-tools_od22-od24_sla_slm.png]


---

## 2. Sewing Presser Feet

Custom sewing presser feet designed for **SINGER 44xx Series Heavy Duty** sewing machines. These feet center the lines and ropes automatically under the needle, ensuring clean, symmetrical, and structural bar-tack sewing splices.

### Material Recommendations
* **Material**: **Photosensitive Resin** printed with **SLA** technology (e.g., CBY resin). Smooth finishing is required to prevent catching on the line fibers.

### Parts list & Design Files
All sewing tools are located in [`sewing/SINGER_44xx/`](sewing/SINGER_44xx):

| Target Line/Rope Diameter | STEP (Parametric) | STL (Print-Ready) | Notes |
|---|---|---|---|
| **1.1mm lines** (e.g. steering lines) | [presser_foot_1.1mm_line_sla.step](sewing/SINGER_44xx/presser_foot_1.1mm_line_sla.step) | [presser_foot_1.1mm_line_sla.stl](sewing/SINGER_44xx/presser_foot_1.1mm_line_sla.stl) | For splicing thin flight lines. |
| **1.4mm lines** (standard lines) | [presser_foot_1.4mm_line_sla.step](sewing/SINGER_44xx/presser_foot_1.4mm_line_sla.step) | [presser_foot_1.4mm_line_sla.stl](sewing/SINGER_44xx/presser_foot_1.4mm_line_sla.stl) | For splicing standard flight lines. |
| **1.7mm lines** (heavy front lines) | [presser_foot_1.7mm_line_sla.step](sewing/SINGER_44xx/presser_foot_1.7mm_line_sla.step) | [presser_foot_1.7mm_line_sla.stl](sewing/SINGER_44xx/presser_foot_1.7mm_line_sla.stl) | For splicing thicker front flight lines. |
| **3mm ropes** (leaders & pigtails) | [presser_foot_3mm_rope_sla.step](sewing/SINGER_44xx/presser_foot_3mm_rope_sla.step) | [presser_foot_3mm_rope_sla.stl](sewing/SINGER_44xx/presser_foot_3mm_rope_sla.stl) | For splicing steering leader lines. |



*Note: The main 4mm sheeting/depower line is too thick for mechanical sewing and must be whipped/sewn manually using whipping twine.*

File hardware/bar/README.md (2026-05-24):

# Bar Component

The **Bar** is the core structural element of ThePerfectKiteBar system. It consists of a carbon fiber tube, two protective **Bar Ends** (which secure the steering/leader lines), and a **Central Piece** (which routes the sheeting and safety lines).

To accommodate different weight and durability requirements, we support two separate sizing tracks based on the carbon tube dimensions:
1. **OD 22mm / ID 20mm Track**: Optimized for lighter weight, smaller hands, and compact/joystick bars.
2. **OD 24mm / ID 22mm Track**: The standard, highly robust profile suitable for all-round conditions.

---

## 1. Bar Ends

The Bar Ends insert 100mm inside the carbon tube to reinforce it against bending stress, channel the steering lines, and provide a secure winding surface.

| Carbon Tube Size | Leader Line | Variant 5 (Standard Sweep) | Variant 7 (Contoured / Reinforced) | Subfolder |
|---|---|---|---|---|
| **OD 22mm / ID 20mm** | 2.5mm max |  |  | [`22mm Bar Ends`](carbon_tube_od22_id20mm/bar_end) |
| **OD 24mm / ID 22mm** | 3.0mm max |  |  | [`24mm Bar Ends`](carbon_tube_od24_id22mm/bar_end) |

---

## 2. Center Pieces

The Central Piece snaps over the middle of the carbon tube. It contains the low-friction entry/exit guide for the polyurethane-covered sheeting lines and safety lines.

All center pieces use the optimized **Variant 7** geometry, but come in two versions based on the securing bolt diameter:

* **2.5mm Bolt version**: Offers a smaller center-recess footprint and maximum weight saving.
* **3mm Bolt version**: Provides a larger, heavier-duty connection for maximum strength.

| Carbon Tube Size | 2.5mm Bolt Version (Compact) | 3mm Bolt Version (Robust) | Subfolder |
|---|---|---|---|
| **OD 22mm / ID 20mm** |  |  | [`22mm Center Piece`](carbon_tube_od22_id20mm/bar_center_piece) |
| **OD 24mm / ID 22mm** |  |  | [`24mm Center Piece`](carbon_tube_od24_id22mm/bar_center_piece) |

---

## Materials & Sourcing

1. **Carbon Tube**:
   - Buy a pull-wound or roll-wrapped carbon fiber tube (3K gloss or matte) with your choice of track dimensions:
     - 22mm outer diameter / 20mm inner diameter (wall thickness 1mm)
     - 24mm outer diameter / 22mm inner diameter (wall thickness 1mm)
   - Cut to your preferred bar length (usually between 45cm and 55cm).
2. **3D Printing**:
   - **Technology**: Selective Laser Sintering (**SLS**) is highly recommended.
   - **Material**: **PA12 Nylon** (unpolished or polished). Avoid SLA or standard FDM PLA/PETG as they lack the impact resistance and flexibility needed for high-load kite control systems.
3. **Hardware**:
   - For 22mm Central Piece: M2.5 or M3 socket head bolt (length 12mm)
   - For 24mm Central Piece: M2.5 or M3 socket head bolt (length 14mm)
   - Glue for Bar Ends: Marine grade epoxy (e.g., West System) or flexible polyurethane adhesive (e.g., 3M 5200).

---

## Native Shapr3D Design Files

The following `.shapr` files are the editable source models created in Shapr3D. Each file includes full parametric definitions—sketches, constraints, and feature history—so you can open and modify them directly in Shapr3D (iOS/iPadOS/macOS).

<!-- BEGIN_SHAPR_TABLE -->
<!-- Auto-generated Shapr3D download table. Do not edit manually. -->
| File | MD5 | Last Modified | Download URL |
|---|-----|---|---|
| `bar-center-piece_22_m2.5x12_sls.shapr` | `dbb2e7d7f3a93d92e606cccd7b349d44` | 2025-05-02 03:57:23 | [Download](https://storage.googleapis.com/theperfectkitebar-cad-assets/bar/carbon_tube_od22_id20mm/bar_center_piece/variant_7/bar-center-piece_22_m2.5x12_sls.shapr) |
| `bar-center-piece_22_m3x12_sls.shapr` | `90e041ad71556d7bbd5cdc6f9af44f42` | 2025-06-07 20:08:35 | [Download](https://storage.googleapis.com/theperfectkitebar-cad-assets/bar/carbon_tube_od22_id20mm/bar_center_piece/variant_7/bar-center-piece_22_m3x12_sls.shapr) |
| `bar-end_22-20_sls.shapr` | `1b0e33c67c1ef51686e6ca508431f07c` | 2025-05-02 03:57:32 | [Download](https://storage.googleapis.com/theperfectkitebar-cad-assets/bar/carbon_tube_od22_id20mm/bar_end/leader_line_2.5mm/variant_5/bar-end_22-20_sls.shapr) |
| `bar-end_22-20_sls.shapr` | `8385ef305bdfa2b8d48de34e286412dc` | 2025-05-02 03:57:29 | [Download](https://storage.googleapis.com/theperfectkitebar-cad-assets/bar/carbon_tube_od22_id20mm/bar_end/leader_line_2.5mm/variant_7/bar-end_22-20_sls.shapr) |
| `bar-center-piece_24_m2.5x14_sls.shapr` | `3e2a95272948cef865253b36069fbe39` | 2025-05-02 03:57:11 | [Download](https://storage.googleapis.com/theperfectkitebar-cad-assets/bar/carbon_tube_od24_id22mm/bar_center_piece/variant_7/bar-center-piece_24_m2.5x14_sls.shapr) |
| `bar-center-piece_24_m3x14_sls.shapr` | `8e1177d5e58f46734cf1eaa8ca534c95` | 2025-06-07 20:08:34 | [Download](https://storage.googleapis.com/theperfectkitebar-cad-assets/bar/carbon_tube_od24_id22mm/bar_center_piece/variant_7/bar-center-piece_24_m3x14_sls.shapr) |
| `bar-end_24-22_sls.shapr` | `fcee6fbcd4184e35ccb0ba590740c003` | 2025-06-07 20:08:35 | [Download](https://storage.googleapis.com/theperfectkitebar-cad-assets/bar/carbon_tube_od24_id22mm/bar_end/leader_line_3mm/variant_5/bar-end_24-22_sls.shapr) |
| `bar-end_24-22_sls.shapr` | `7ca763e76f91d14a8032e5b38f5cebf3` | 2025-06-07 20:08:35 | [Download](https://storage.googleapis.com/theperfectkitebar-cad-assets/bar/carbon_tube_od24_id22mm/bar_end/leader_line_3mm/variant_7/bar-end_24-22_sls.shapr) |
<!-- END_SHAPR_TABLE -->

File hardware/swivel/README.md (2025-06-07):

# Swivel

A standard component of any kite control bar — designed to prevent flying lines from twisting during use.

This swivel is optimized for:
- **4mm Dyneema** main sheeting line (inside a Dyneema chafe sleeve suitable for 4–6mm rope)
- **2.5mm safety line** (non-bungee type)

---

## Bearing Requirement

To assemble this swivel, you will need a **ceramic thrust bearing**.

### Bearing Specification:
- Type: **Zirconia Thrust Ball Ceramic Bearing**  
- Model: **51103**  
- Dimensions:  
  - Inner Diameter (ID): 17mm  
  - Outer Diameter (OD): 30mm  
  - Height (H): 9mm  

### Suggested Product:
Available from:
- **AliExpress**  
- **Alibaba**  
- Direct from manufacturers like:  
  [Lily Bearing - 51103 Ceramic Bearing](https://www.lily-bearing.com/products/ce51103zr/)

---

## 3D Printing Instructions

Both the **swivel housing** and **swivel shaft** are designed to be 3D printed from **316 stainless steel** using **SLM technology (Selective Laser Melting)**.

---

### Material & Technology
- Material: **316 Stainless Steel**  
- Printing Method: **SLM (Selective Laser Melting)**

> SLM is a metal 3D printing technology that uses a high-power laser to fully melt metal powder, layer by layer, into solid parts. It produces highly durable and functional metal components suitable for structural applications.

Learn more: [https://jlc3dp.com/3d-printing/selective-laser-melting](https://jlc3dp.com/3d-printing/selective-laser-melting)

---

## Printing Notes
- Recommended print orientation: minimize support contact on critical surfaces.  
- Consider post-processing (vibratory polishing or manual smoothing) for smoother line contact areas.  
- Ensure correct tolerances for bearing fit.  
- Clean all support removal points carefully.

---

## Assembly Notes
- Insert the ceramic bearing carefully into the swivel housing.  
- The bearing should seat snugly without forcing.  
- Ensure smooth rotation after assembly.

---

## Summary of Components
| Part | Material | Manufacturing Method |
|---|---|---|
| Swivel Housing | 316 Stainless Steel | SLM Metal 3D Printing |
| Swivel Shaft | 316 Stainless Steel | SLM Metal 3D Printing |
| Bearing | Zirconia Ceramic | Purchased (51103 model)  |

## Native Shapr3D Design Files

The following `.shapr` files are the editable source models created in Shapr3D. Each file includes full parametric definitions—sketches, constraints, and feature history—so you can open and modify them directly in Shapr3D (iOS/iPadOS/macOS).

<!-- BEGIN_SHAPR_TABLE -->
<!-- Auto-generated Shapr3D download table. Do not edit manually. -->
| File | MD5 | Last Modified | Download URL |
|---|-----|---|---|
| `swivel-cap_sls.shapr` | `1715559d852b7dfd9414abf99c1e8d5d` | 2025-06-07 20:08:35 | [Download](https://storage.googleapis.com/theperfectkitebar-cad-assets/swivel/sheeting_rope_4mm/bearing_ZR51103/swivel-cap/variant_4/swivel-cap_sls.shapr) |
| `swivel_4.5x17x3x9_slm.shapr` | `8903e0fc5c8f5b3c1035ddb2334a7ffc` | 2025-05-02 03:57:08 | [Download](https://storage.googleapis.com/theperfectkitebar-cad-assets/swivel/sheeting_rope_4mm/bearing_ZR51103/swivel_housing_and_shaft/variant_4/swivel_4.5x17x3x9_slm.shapr) |
| `swivel_5x17x3x9_slm.shapr` | `5beec6918e9ec438ad74d79805c2baa0` | 2025-06-07 20:08:34 | [Download](https://storage.googleapis.com/theperfectkitebar-cad-assets/swivel/sheeting_rope_4mm/bearing_ZR51103/swivel_housing_and_shaft/variant_4/swivel_5x17x3x9_slm.shapr) |
<!-- END_SHAPR_TABLE -->

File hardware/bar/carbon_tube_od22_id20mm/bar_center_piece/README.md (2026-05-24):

# Central Piece for 22mm Carbon Tube (OD 22mm / ID 20mm)

This directory contains the design files and specifications for the **Central Piece** of ThePerfectKiteBar system, specifically designed to fit a **22mm outer diameter** carbon tube.

---

## Design Overview

The central piece guides the sheeting and safety lines through the center of the control bar. **Variant 7** is the culmination of design iterations focused on high strength, smooth control line travel, clean aesthetics, and secure heat-shrink tubing integration.

### Variant 7 Versions
The central piece is available in two versions based on the securing bolt size:

| Version | Securing Bolt | Description | Image Preview |
|---|---|---|---|
| **2.5mm Bolt** | M2.5 x 12mm | Most compact, lightweight profile. Recommended for short or joystick-style bars. |  |
| **3mm Bolt** | M3 x 12mm | Slightly bulkier but highly robust version for maximum durability under heavy load. |  |

Choose the version that fits your priority: **lightweight minimalism (2.5mm)** or **maximum durability (3mm)**.

---

## Specifications

- **Compatibility**: Carbon Tube with Outer Diameter (OD) = 22mm, Inner Diameter (ID) = 20mm
- **Manufacturing Technology**: **SLS 3D Printing** (Selective Laser Sintering)
- **Material**: **PA12 Nylon** (offers the ideal blend of flexibility, impact resistance, and weatherability)
- **Files**: See [`variant_7`](variant_7) for `.step`, `.stl`, and `.shapr` source models.

---

## Assembly & Installation

Thanks to the elasticity and strength of the SLS PA12 Nylon material, this central piece can be snapped over the carbon tube directly without fully disassembling the bar ends.

### Tools Required
- Hex Allen key (size matching your bolt choice)
- Awl or small hook (to undo knots in the trim line)
- Long-nose pliers

### Installation Steps
1. Neatly wind your control lines up to the V-splitter.
2. Remove the trim system.
3. Remove the sheeting and safety lines.
4. Remove the old/broken central piece.
5. Gently expand the new central piece and snap it directly over the middle of the carbon tube.
6. Align it, insert and tighten the securing bolt (do not overtighten).
7. Re-thread the sheeting/safety lines and reinstall the trim system.

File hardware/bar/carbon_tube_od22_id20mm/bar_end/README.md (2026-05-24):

# Bar Ends for 22mm Carbon Tube (OD 22mm / ID 20mm)

This directory contains the design files and specifications for the **Bar Ends** designed to fit a **22mm outer diameter / 20mm inner diameter** carbon tube.

---

## Design Overview

The Bar Ends secure the leader lines (steering lines) to the control bar, provide a comfortable hand grip area, and allow the lines to be wound up neatly when not in use. 

This track uses a **2.5mm channel** designed for **2.5mm leader lines**.

### Variants
We support two variants depending on your preferred bar-end sweep, line attachment style, and geometry:

| Variant | Description | Image Preview |
|---|---|---|
| **Variant 5** | Traditional sweep-back angle with optimized weight saving and standard leader line channel routing. Fits the standard bar-end knob. |  |
| **Variant 7** | Refined geometry featuring an updated sweep profile, smoother line entry contours, and a more robust connection socket to prevent stress-fractures under high steering forces. |  |

Both variants require matching **Bar End Knobs** (`bar-end-knob_22-20_sls.stl`) to plug the outer opening and secure the internal knots.

---

## Specifications

- **Compatibility**: Carbon Tube with OD = 22mm, ID = 20mm
- **Leader Line Size**: 2.5mm
- **Manufacturing Technology**: **SLS 3D Printing**
- **Material**: **PA12 Nylon**
- **Insertion Depth inside Tube**: 100mm (ensures rigidity and prevents bending moments from cracking the carbon tube)
- **Files**:
  - Variant 5 files: [`leader_line_2.5mm/variant_5`](leader_line_2.5mm/variant_5)
  - Variant 7 files: [`leader_line_2.5mm/variant_7`](leader_line_2.5mm/variant_7)

---

## Assembly & Installation

1. **Dry Fit**: Slide the bar end socket into the carbon tube. It should be a snug fit. If it's too tight, lightly sand the insert diameter of the plastic piece. If it's loose, wrap a single layer of electrical tape around the insert.
2. **Adhesive**: Apply a high-quality marine epoxy or polyurethane adhesive (such as 3M 5200) inside the carbon tube and on the insert of the bar end.
3. **Insert & Align**: Push the bar end fully into the carbon tube, ensuring the sweep direction is aligned correctly on both ends. Wipe away any excess squeeze-out adhesive.
4. **Leader Line Routing**: Feed the leader line through the internal routing channel.
5. **Secure Knob**: Secure the leader line with a figure-eight knot, slide it into the recess, and snap/epoxy the **Bar End Knob** into place to seal the assembly.

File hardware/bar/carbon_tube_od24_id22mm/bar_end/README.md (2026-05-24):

# Bar Ends for 24mm Carbon Tube (OD 24mm / ID 22mm)

This directory contains the design files and specifications for the **Bar Ends** designed to fit a **24mm outer diameter / 22mm inner diameter** carbon tube.

---

## Design Overview

The Bar Ends secure the leader lines (steering lines) to the control bar, provide a comfortable hand grip area, and allow the lines to be wound up neatly when not in use. 

This track uses a **3mm channel** designed for **3mm leader lines**.

### Variants
We support two variants depending on your preferred bar-end sweep, line attachment style, and geometry:

| Variant | Description | Image Preview |
|---|---|---|
| **Variant 5** | Traditional sweep-back angle with optimized weight saving and standard leader line channel routing. Fits the standard bar-end knob. |  |
| **Variant 7** | Refined geometry featuring an updated sweep profile, smoother line entry contours, and a more robust connection socket to prevent stress-fractures under high steering forces. |  |

Both variants require matching **Bar End Knobs** (`bar-end-knob_24-22_sls.stl`) to plug the outer opening and secure the internal knots.

---

## Specifications

- **Compatibility**: Carbon Tube with OD = 24mm, ID = 22mm
- **Leader Line Size**: 3mm
- **Manufacturing Technology**: **SLS 3D Printing**
- **Material**: **PA12 Nylon**
- **Insertion Depth inside Tube**: 100mm (ensures rigidity and prevents bending moments from cracking the carbon tube)
- **Files**:
  - Variant 5 files: [`leader_line_3mm/variant_5`](leader_line_3mm/variant_5)
  - Variant 7 files: [`leader_line_3mm/variant_7`](leader_line_3mm/variant_7)

---

## Assembly & Installation

1. **Dry Fit**: Slide the bar end socket into the carbon tube. It should be a snug fit. If it's too tight, lightly sand the insert diameter of the plastic piece. If it's loose, wrap a single layer of electrical tape around the insert.
2. **Adhesive**: Apply a high-quality marine epoxy or polyurethane adhesive (such as 3M 5200) inside the carbon tube and on the insert of the bar end.
3. **Insert & Align**: Push the bar end fully into the carbon tube, ensuring the sweep direction is aligned correctly on both ends. Wipe away any excess squeeze-out adhesive.
4. **Leader Line Routing**: Feed the leader line through the internal routing channel.
5. **Secure Knob**: Secure the leader line with a figure-eight knot, slide it into the recess, and snap/epoxy the **Bar End Knob** into place to seal the assembly.

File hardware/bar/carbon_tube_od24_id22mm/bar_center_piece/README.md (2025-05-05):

# Central Piece installed on carbon tube (od 24, 22mm ...) 

Central piece for a **24mm** carbon tube — Variant 7.

Variant 7 is the result of many design iterations focused on:
- Robustness
- Aesthetics
- Minimal offset from the bar center
- Secure installation of heat-shrink tubing

---

## Notes on Versions

The central piece comes in two versions based on the bolt size:

| Version | Description | Recommended Use |
|---|---|---|
| 3mm Bolt | Most robust, "bomb-proof" option | Recommended for maximum durability |
| 2.5mm Bolt | Lighter, more compact version with a smaller footprint in the bar center | For those prioritizing weight saving |

Choose the version based on your specific needs — maximum strength or lightweight minimalism.

---

## Assembly Instructions

*(Detailed guide to be added later.)*

### Quick Note:
The central piece can be installed without fully disassembling the entire bar.

Thanks to the flexibility of PA12 material, the part can be gently expanded and snapped over the bar without removing the end pieces.

---

### Installation Steps (Minimal Disassembly)

1. Wind up the lines onto a bottle or similar object, all the way up to the V-splitter.
2. Remove the trim system.
3. Remove the sheeting and safety lines.
4. Carefully remove the broken central piece.
5. Gently expand the new central piece and snap it onto the bar.
6. Reinstall the sheeting and safety lines.
7. Reinstall the trim system.
8. Done!

---

### Tools Required
- Allen key (hex key)  
- Awl (to undo trim rope knot)  
- Long nose pliers (to pull trim knot through)  

---

## Benefits of This Method
- No need to remove the bar end pieces.  
- Faster replacement with minimal effort.  
- Simple field-repair possible with basic tools.

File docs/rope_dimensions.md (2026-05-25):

# Rope Splicing & Cutting Dimensions Companion Guide

This document serves as the companion guide to the unified [Interactive Rope Splicing & Sizing Calculator](https://raw.githack.com/aniva/theperfectkitebar/main/docs/rope_calculator.html). It explains the routing physics, splicing guidelines, and mathematical models for building a premium, custom kiteboarding control bar.

The system parameters are classified into three main groups to match the labeling on the interactive routing schematic:
- **Group A (Sheeting Rope & Throw)**: Main sheeting line specs, throw length, loop ends, and tail lengths.
- **Group B (Hardware & Trim Geometry)**: Control bar, cleat, block dimensions, and system adjustment travel distances.
- **Group C (Rigging & Splicing)**: Splicing shrinkage factors, leader line adjustments, and pigtail sizing targets.

---

## 1. System Components & Routing

### Desired Throw `(A1)`
The **Throw** is the single line running from the control bar center up to the cleat. It defines the physical range of depower available by sliding the bar.
* **Range**: 40 cm to 70 cm (default is 65 cm).
* **Formula Impact**: A longer throw increases the raw sheeting line length by twice the throw length (due to the 2:1 loop design above the cleat) and increases the length of the chafe sleeve.

### Sheeting Line Diam. `(A2)`
The diameter of the primary sheeting line (4.0mm Dyneema). Fixed at `0.4 cm`.

### Splice Loop Length `(A3)`
The finished splice loop length stitched at the bottom of the sheeting line to anchor it to the quick release. Fixed at `4 cm`.

### Depower Line Tail `(A4)`
The tail of the sheeting line exiting the left side of the cleat, ending with a cylindrical blue pull handle. Fixed at `9 cm` for grip and leverage.

---

### Bar Diameter `(B1)`
The outer diameter of the hollow carbon control bar (21 mm, 22 mm, 23 mm, or 24 mm). It guides the leader lines inside the bar ends.

### Cleat Dimensions `(B2, B3, B4)`
The **Cleat** secures the sheeting line at the top of the throw.
* **Cleat Length (B2)**: Fixed at `6 cm`.
* **Cleat Width (B3)**: Fixed at `1 cm`.
* **Cleat Holes (B4)**: Fixed at `4` routing holes.

### Upper Block Dimensions `(B5, B6)`
The **Upper Block** is the pulley redirection unit at the top of the trim system.
* **Upper Block Diam. (B5)**: Fixed at `1.0 cm`.
* **Upper Block Height (B6)**: Fixed at `2.5 cm`.

### Depower Move [Cleat to Block] `(B7)`
The **Depower Move** represents the physical distance between the Cleat (B2) and the Upper Block (B6) when fully extended. It determines the maximum adjustment travel of the trim system.
* **Range**: 10 cm to 50 cm (default is 25 cm).

### Depower Ratio `(B8)`
The **Depower Ratio** is the 2:1 block-and-tackle mechanical advantage of the trim adjustment loops. Fixed at `1/2`.

---

#### Splicing Specs & Adjustable Parameters `(Group C)`
These parameters are adjustable via left-right sliders in the main calculator:
* **Splicing Shrinkage**: General shrinkage rate applied to any splice. Range `10%` to `30%` (default `20%`).
* **Bury Ratio**: General bury length multiplier. Range `40x` to `60x` rope diameter (default `50x`).
* **Leader Adjustment (C2)**: Adjustment span for leader lines. Range `20` to `50` cm (default `30` cm).
* **Power Pigtail Adjustment**: Front line trim adjuster span. Range `10` to `30` cm (default `20` cm). Pigtail Finished Length (C4) must always be at least 20cm longer than this.
* **Pigtail Finished Length (C4)**: Raw base finished target length. Range `30` to `50` cm (default `40` cm). Must always be at least 20cm longer than the Power Pigtail Adjustment.

---

## 2. Splicing Formulas Reference

These formulas are implemented dynamically in the [Interactive Calculator](https://raw.githack.com/aniva/theperfectkitebar/main/docs/rope_calculator.html):

### Sheeting Line Sizing
* **Required Rope Length**:
  $$\text{Required Length} = (\text{Throw} \times 2) + \frac{\text{Depower Move}}{\text{Depower Ratio}} + \text{Line Tail} + \text{Splice Loop} + \text{Block Height} - 10\text{ cm}$$
  * *Example (65cm Throw, 25cm Move)*: $(65 \times 2) + (25 / 0.5) + 9 + 4 + 2.5 - 10 = 185.5\text{ cm}$

### Steering Leader & Safety Line Sizing
* **Leader Line Required Rope Length**:
  $$\text{Leader Required} = (\text{Throw} + \text{Depower Move} + \text{Leader Adjustment}) \times (1 + \text{Splicing Shrinkage}) + \text{Leader Adjustment}$$
  * *Example (65cm Throw, 25cm Move, 30cm Leader Adjustment, 20% Splicing Shrinkage)*: $(65 + 25 + 30) \times (1 + 0.20) + 30 = 174.0\text{ cm}$
* **Safety Line Required Rope Length**:
  $$\text{Safety Required} = \text{Sheeting Required} - \text{Depower Move}$$
  * *Example (185.5cm Sheeting, 25cm Move)*: $185.5 - 25 = 160.5\text{ cm}$

### Steering & Power Pigtails
* **Splicing Bury**: $\text{Bury} = \text{Rope Diameter} \times \text{Bury Ratio}$
  * *Example (0.30 cm Rope Diameter for 24mm Bar OD, 50x Bury Ratio)*: $0.30 \times 50 = 15.0\text{ cm}$
  * *Example (0.25 cm Rope Diameter for 22mm Bar OD, 50x Bury Ratio)*: $0.25 \times 50 = 12.5\text{ cm}$
* **Steering Pigtail (Loop-to-Loop)**:
  $$\text{Steering Pigtail} = \text{Finished Length} + 2 \times \text{Bury} \times (1 + \text{Splicing Shrinkage}) + \text{Loop Knot Length} + \text{Pigtail Loop Length}$$
  * *Example (40cm Finished Length, 15cm Bury, 20% Splicing Shrinkage, 4cm Knot, 3.5cm Loop)*: $40 + 2 \times 15 \times 1.20 + 4 + 3.5 = 83.5\text{ cm}$
* **Power Pigtail (Adjustable Loop-to-Knot)**:
  $$\text{Power Pigtail (Adjustable)} = \text{Finished Length} + 2 \times \text{Bury} \times (1 + \text{Splicing Shrinkage}) + \text{Power Adjustment} + \text{Pigtail Loop Length}$$
  * *Example (40cm Finished Length, 15cm Bury, 20% Splicing Shrinkage, 20cm Power Adjustment, 3.5cm Loop)*: $40 + 2 \times 15 \times 1.20 + 20 + 3.5 = 99.5\text{ cm}$

### Accessories & Chafe Sleeve
* **Bungee for 65mm Bar End**: $30.0\text{ cm}$ ($25\text{cm base} + 5\text{cm tail}$)
* **Bungee for 100mm Bar End**: $24.0\text{ cm}$ ($19\text{cm base} + 5\text{cm tail}$)
* **PU length for bar end (half for each end)**: $100\text{ mm}$ (default)
* **Safety Bungee for QR**: $35.0\text{ cm}$ (2.5mm elastic core)

---

## 3. Recommended Build Procedure

1. **Calculate & Cut**: Enter your desired throw and depower move in the [Interactive Calculator](https://raw.githack.com/aniva/theperfectkitebar/main/docs/rope_calculator.html) to obtain your custom target lengths.
2. **Sheeting Line Splice**:
   * Splice the 4 cm loop at one end of the 4.0mm sheeting line.
   * Lock-stitch the bury.
   * Feed the line through the bar center, cleat base, upper block, and trim cleat.
   * Cut the excess line once the finished length is reached, leaving a 9 cm tail.
3. **Bungee Threading**:
   * Cut a 32.5 cm piece of 2.5mm bungee elastic core.
   * Insert the bungee core inside the 2.5mm Dyneema bungee line. The line will bunch up and shrink by 33%.
   * Splice the leader line loops at the target finished dimensions.
4. **Pigtail Rigging**:
   * Splice loops at both ends of the steering pigtails (loop-to-loop connection).
   * Splice the power pigtails with adjustable loops on one end and stopper knots on the other.

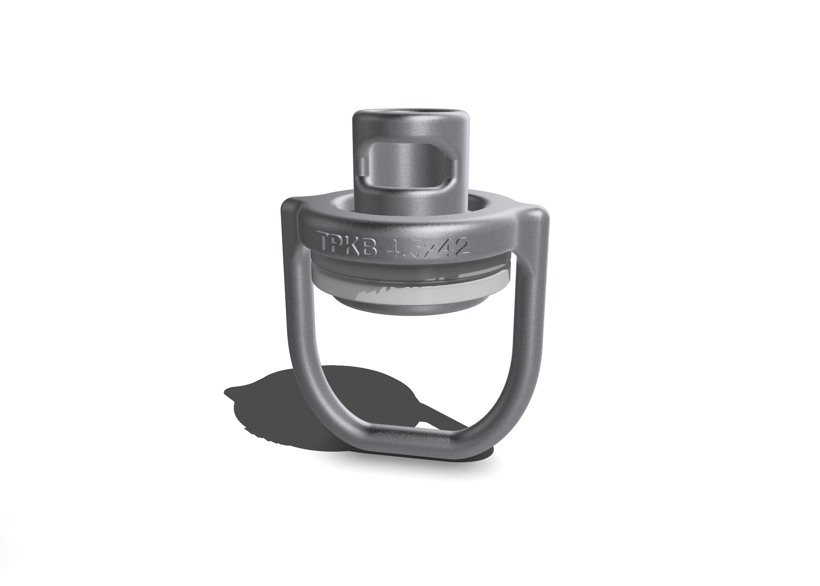
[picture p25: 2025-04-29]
hardware/swivel/sheeting_rope_4mm/bearing_ZR51103/swivel_housing_and_shaft/variant_4/swivel_4.5x17x3x9_slm.png

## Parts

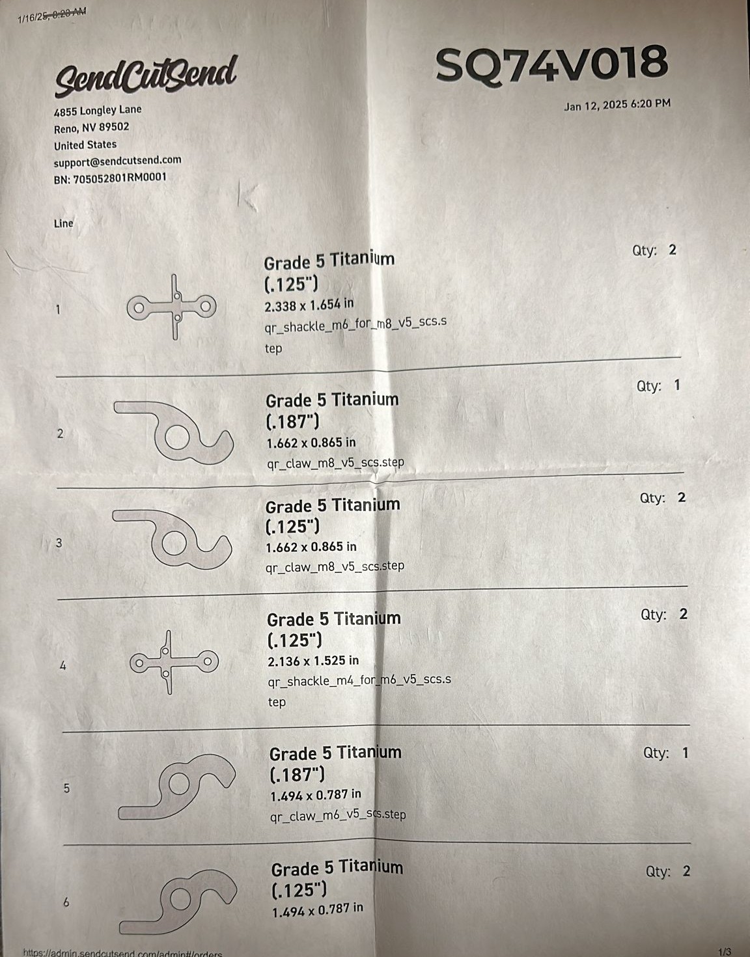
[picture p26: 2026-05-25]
images/send_cut_send_order_sample.jpg

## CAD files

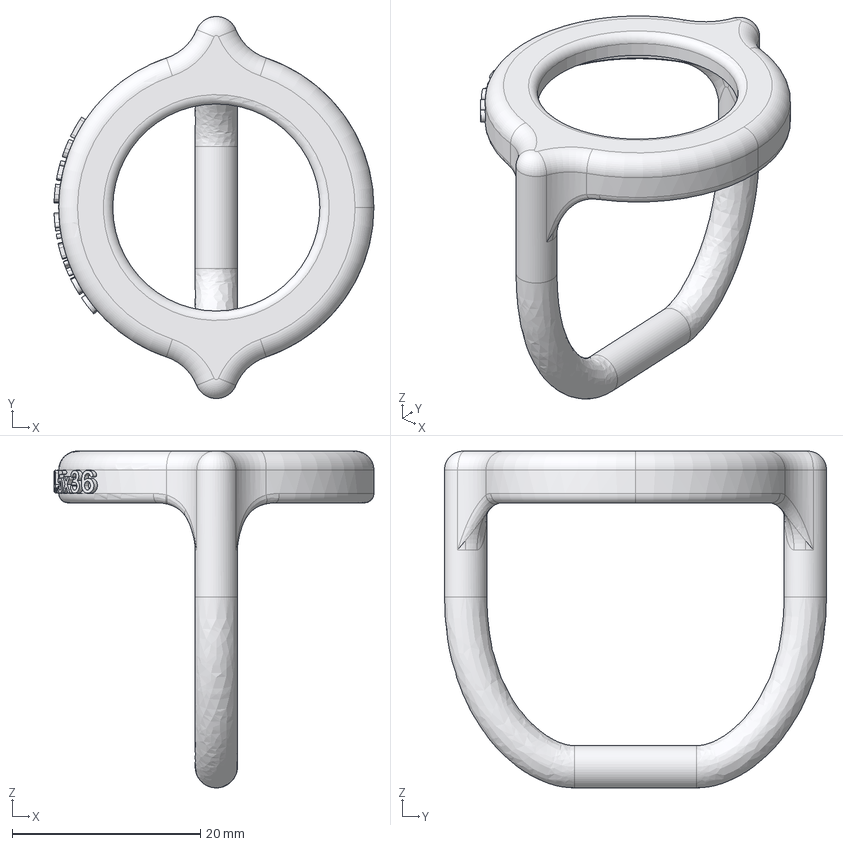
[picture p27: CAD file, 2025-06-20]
hardware/swivel/sheeting_rope_4mm/bearing_ZR51103/swivel_housing_and_shaft/variant_4/swivel-housing_4.5x36x17x3x9_slm.step
34.0 x 40.6 x 35.8 mm
print checks
LILY_51103_PART4 x 14
LILY_51103_PART3
LILY_51103_PART2
LILY_51103_PART1

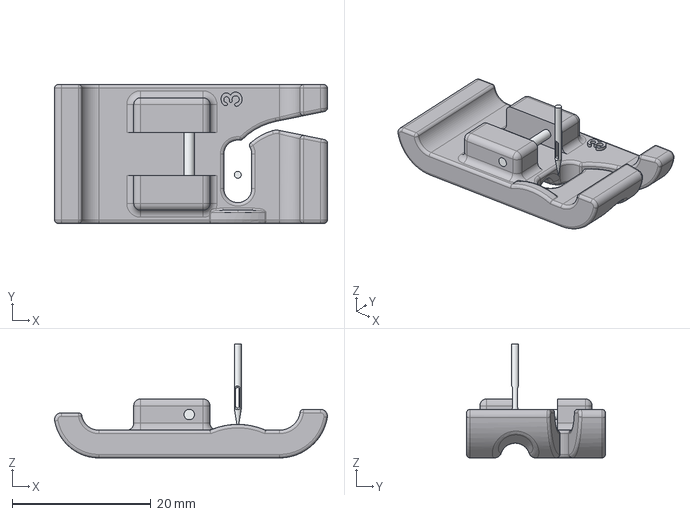
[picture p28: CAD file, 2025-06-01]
hardware/tools/sewing/SINGER_44xx/presser_foot_3mm_rope_sla.step
39.3 x 20.0 x 16.4 mm

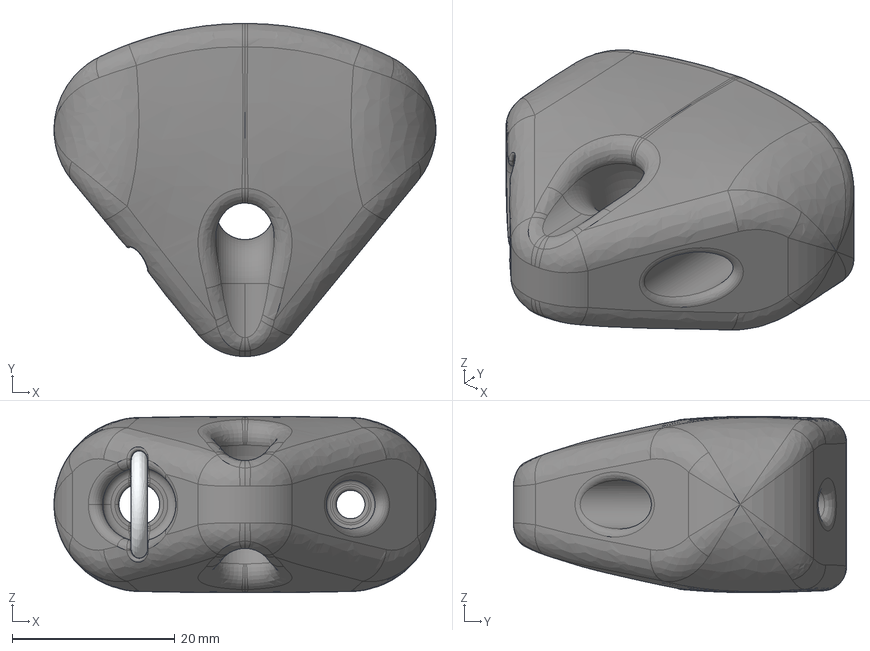
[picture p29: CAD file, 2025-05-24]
hardware/trim/sheeting_rope_6mm/front_line_2mm/v-splitter/variant_1/v-splitter_6x20_mjf.step
47.0 x 41.0 x 21.7 mm

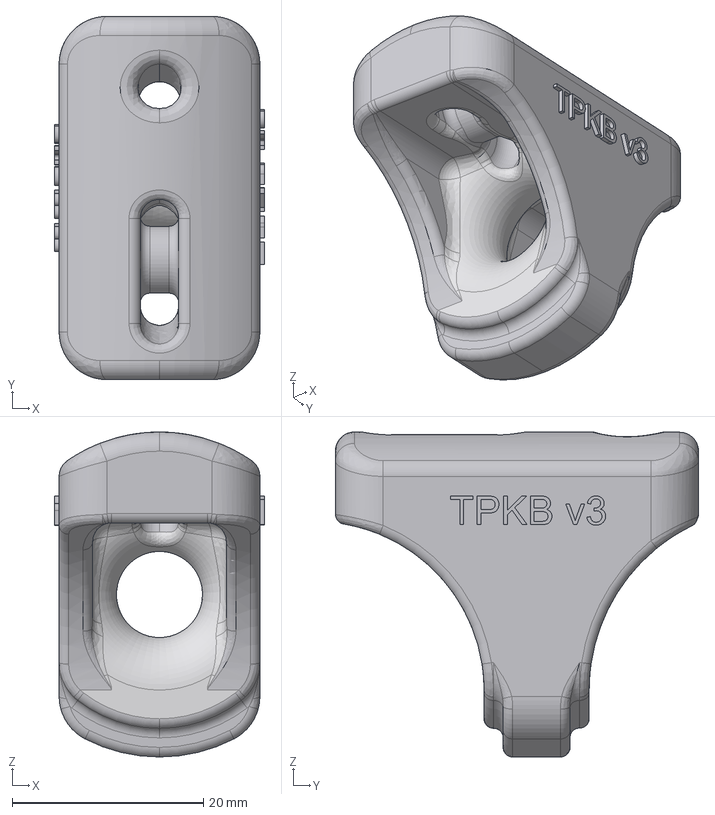
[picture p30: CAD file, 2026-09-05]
hardware/trim/sheeting_rope_8mm/front_line_2mm/v-splitter/variant_3/v-splitter_8x2_mjf.step
22.0 x 38.0 x 34.0 mm

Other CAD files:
hardware/bar/carbon_tube_od22_id20mm/bar_center_piece/variant_7/bar-center-piece_22_m2.5x12_sls.step
hardware/bar/carbon_tube_od22_id20mm/bar_end/leader_line_2.5mm/variant_5/bar-end_22-20_sls.step
hardware/bar/carbon_tube_od22_id20mm/bar_end/leader_line_2.5mm/variant_7/bar-end_22-20_sls.step
hardware/bar/carbon_tube_od24_id22mm/bar_center_piece/variant_7/bar-center-piece_24_m2.5x14_sls.step
hardware/bar/carbon_tube_od24_id22mm/bar_end/leader_line_3mm/variant_5/bar-end_24-22_sls.step
hardware/bar/carbon_tube_od24_id22mm/bar_end/leader_line_3mm/variant_7/bar-end_24-22_sls.step
hardware/swivel/sheeting_rope_4mm/bearing_ZR51103/swivel-cap/variant_4/swivel-cap_sls.step
hardware/trim/sheeting_rope_4mm/cleat/variant_3/cleat-base_stopper_4_mjf.step
hardware/trim/sheeting_rope_4mm/front_line_1.4mm/safety_stopper/variant_3/line_stopper_14_mjf.step
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

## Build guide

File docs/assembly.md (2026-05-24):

# How to assemble ThePerfectKiteBar

For line cutting targets and rope splicing lengths, refer to the [Rope Splicing & Cutting Dimensions](rope_dimensions.md) guide.

## Tools Required

You will need the following tools to assemble the bar:

- **Hacksaw** – For cutting carbon fiber tube.  
- **Drill** – For precision hole-making.  
- **Measuring Tape** – Ensures accurate component placement.  

## EVA Non-Slip Heat Shrink Tube Installation

To install the **EVA non-slip heat shrink tube**, follow these steps:

1. Use **100°C boiling water** or a **heat gun** to shrink the tube.  
2. If using a heat gun, apply heat evenly, working from **one end to the middle**, while slowly rotating the bar.  
3. Ensure the tube is **fully heated**; **insufficient heating may cause slipping or stretching** during use.  
4. EVA heat shrink tubing typically **does not shrink lengthwise**, so you can cut it **to the exact required length** before installation.  
5. **Cutting tip:** Use a **scalpel** to cut the tube while it is flat for a clean edge.  
6. **Recommended tube size:**  
   - **25mm diameter** tube fits both **OD 24mm carbon tubes** and **OD 22mm carbon tubes**.  

## Testing and Tuning

Before using **ThePerfectKiteBar**, ensure optimal performance by following these steps:

- **Strength Testing** – Apply load gradually to verify the bar’s durability.  
- **Balance Check** – Ensure the control bar is symmetrical for even response.  
- **Line Tension Adjustment** – Tune the flying lines for **optimal kite control**.

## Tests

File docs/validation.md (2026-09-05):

# Validation Status

This register distinguishes reported field experience from recorded test evidence. It does not certify a component or establish a safe operating load.

| Scope | Recorded status | Evidence and remaining work |
| --- | --- | --- |
| First functional bar | Field testing reported in spring 2024 | Root README; exact tested commit, configuration, loads, and results are not recorded here. |
| Printed materials | Multi-season use reported | Root README describes conditions; component-specific test records remain to be added. |
| Quick release variants 1–4 | Did not proceed to field testing | Quick-release README; omitted from published variants. |
| Quick release variant 5 | Formal validation record absent | Manufacturing instructions are available; document the tested configuration and results before assigning a validated status. |
| Quick release variant 6 (M4 and M6) | Experimental; not field-tested according to component documentation | The documented risk of accidental pin release remains unresolved. See the [component warning](../hardware/quick_release/README.md#variant-6). |

## Outstanding work

- [ ] Record exact component variants and Git commits for previously reported field tests.
- [ ] Record test methods, conditions, measurements, and outcomes for the quick-release variants.
- [ ] Resolve and document variant 6 pin-retention behavior before changing its experimental status.
- [ ] Associate any release with a component inventory and the validation records applicable to it.

## Recording a result

For each test, add a dated entry with the tester, component and variant, Git commit, CAD source hash, materials, manufacturing method, assembly configuration, test method, measured loads or conditions, outcome, and links to photos or measurements. Record failures and limitations. Change a status only when supporting evidence is available.

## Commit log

2025-04-29 Initial clean repo without .shapr files
    [bar-center-piece_22_m2.5x12_sls.step, bar-center-piece_22_m2.5x12_sls.stl, bar-center-piece_22_m3x12_sls.step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]
2025-04-29 Remove previously broken .stl files
    [bar-center-piece_22_m2.5x12_sls.stl, bar-center-piece_22_m3x12_sls.stl, bar-center-piece_24_m2.5x14_sls.stl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]
2025-04-29 Re-add valid .stl files for GitHub preview
2025-05-04 Add note about 3d printing warning
2025-05-24 new variant of v-splitter
    [v-splitter_6x20_mjf.step, v-splitter_6x20_mjf.stl]
2025-05-31 added tools
    [alignment_jig_od22_sla.step, alignment_jig_od22_sla.stl, alignment_jig_od24_sla.step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]
2025-06-01 tool for sewing - presser foot models added
    [presser_foot_1.1mm_line_sla.step, presser_foot_1.1mm_line_sla.stl, presser_foot_1.4mm_line_sla.step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]
2025-06-20 added 36mm housing
    [swivel-housing_4.5x36x17x3x9_slm.step, swivel-housing_4.5x36x17x3x9_slm.stl, swivel-shaft_17x3x9_slm.step]
2025-08-31 clean up of qr files, chagning to dfx for laser cut
    [qr-claw_m6_0.187in_for_shackle_m4.step, qr-claw_m6_for_shackle_m4.dxf, qr_claw_m6_0.125in_for_shackle_m4_2x.step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]
2025-09-01 dfx files added for all qr parts
    [qr-claw_m8_for_shackle_m6.dxf, qr_shackle_m6.dxf]
2025-09-07 some renaming for consistency
    [qr-shackle_m4-clpin_m6.dxf, qr-shackle_m4.dxf, qr-shackle_m6-clpin_m6.dxf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]
2026-05-24 Update root Bar README and create missing subfolder READMEs for 22mm and 24mm variants
2026-05-24 Update Tools and Trim READMEs with STL/STEP file links, Cleat Base details, and variant descriptions
2026-05-25 Correct steering and power pigtail formulas to match spreadsheet inputs
2026-05-25 Enforce physical dependency between Power Adjustment and Pigtail Finished Length (C4 >= Adjustment + 20cm)
2026-09-05 Update 8mm V-splitter variant 3 CAD exports and preview
    [v-splitter_8x2_mjf.step, v-splitter_8x2_mjf.stl]
2026-09-05 Update material guide and prefer PA11-HP for V-splitters
2026-10-26 Add Variant 8 bolt pattern and drilling jig note
2026-10-26 Add swivel assembly and cap preview images to swivel README
